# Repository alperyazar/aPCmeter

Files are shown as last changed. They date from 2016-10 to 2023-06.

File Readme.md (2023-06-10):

# aPCmeter

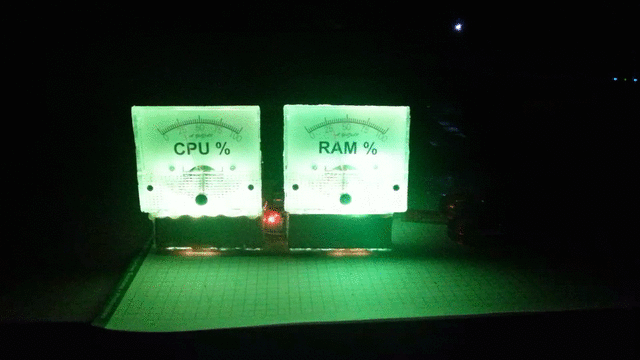
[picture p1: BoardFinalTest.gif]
aPCmeter Working


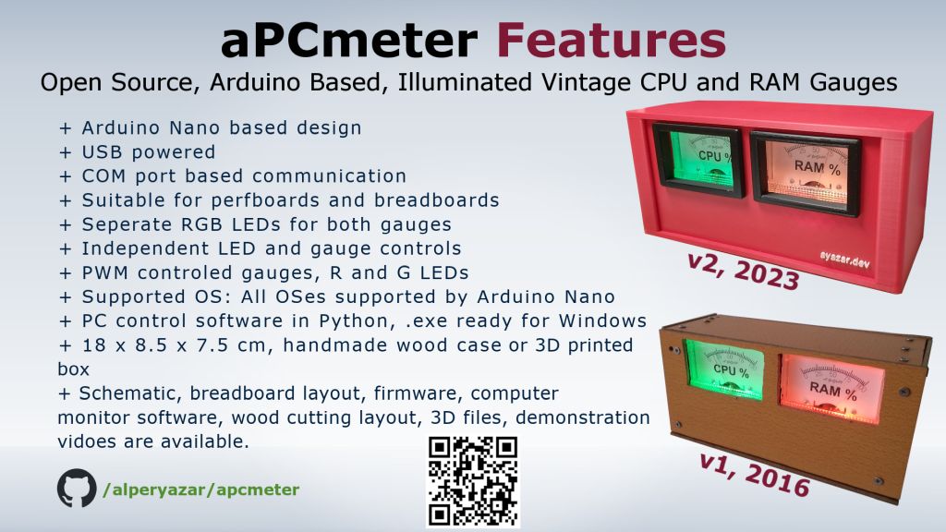
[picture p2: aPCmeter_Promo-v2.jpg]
aPCmeter Flyer


aPCmeter is an open source, Arduino Nano based, illuminated vintage looking CPU and RAM gauges box project. It was designed only just for fun. It shows CPU and RAM utilization of PC in an analog manner.

**AS IS, ABSOLUTELY NO WARRANTY**

## v2, 2023

7 years after the first design (v1, 2016), my friend [Erdal Mehmetcik](https://www.linkedin.com/in/erdal-mehmetcik-7470363a/) who is a 3D printer enthusiast designed and printed an ABS box for me (with [Bambu X1c](https://bambulab.com/en/x1)) and I did a *retrofit*.

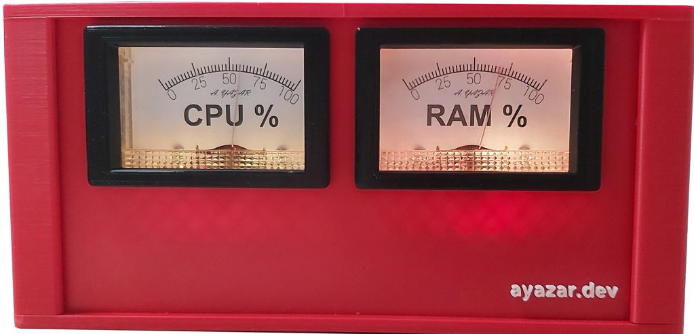
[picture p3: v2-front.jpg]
v2 front


## v2, 2023 vs v1, 2016

The only difference between v2 and v1 is the box design. When I created the project in 2016, 3D printers were not widespread. Therefore, I made a wooden box. In 2023, the box is upgraded to a 3D printed ABS. The electronics, firmware and software are the same.

## Folders

* `3D`: `.stl` files of the new box (v2). You can create your own copy with a 3D printer.

* `Board`: Contains schematic and bread board layout drawn by using Fritzing, BOM and Arduino Nano pinout diagram.

* `Firmware`: Contains Arduino software and its documentation generated by using Doxygen. Doxygen codes are also included there.

* `HowToBuild`: Contains detailed building guide for the hardware.

* `Gauge`: Contains drawings of CPU and RAM gauges in both vector and static formats. All vector drawings were done in Inkscape.

* `Software`: Contains PC software (Python script + `.exe`) required getting CPU and RAM usages from OS and sending them to aPCmeter.

* `Wood`: Contains wood cut sketch prepared by using simple-cutting-software-x. You may take these drawings as a reference if you are planning to build your own wood case.

## Building your own aPCmeter

This is a basic project. First read `HowToBuild`. The schematic is in `Board` directory. The necessary Arduino firmware is in `Firmware` directory with a very detailed documentation. An example PC software is in `Software` directory. If you want to print your own plastic box, then check `3D` directory or for check `Wood` directory to make your own wooden box.

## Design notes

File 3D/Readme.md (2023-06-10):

# 3D

Here, `.stl` files required to print the v2, 2023 box design by a 3D printer are given. The box was designed by my friend, [Erdal Mehmetcik](https://www.linkedin.com/in/erdal-mehmetcik-7470363a/).

- `body.stl`

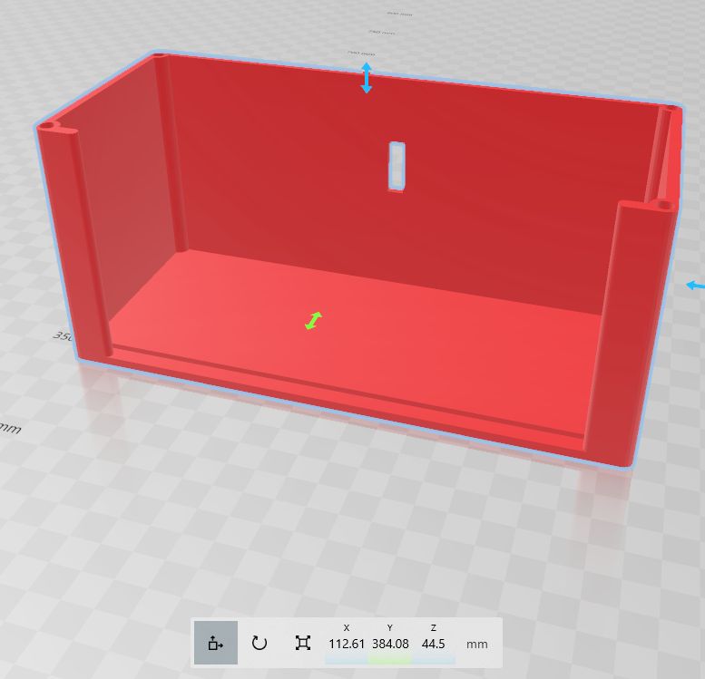
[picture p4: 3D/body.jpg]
body


- `bottom.stl`

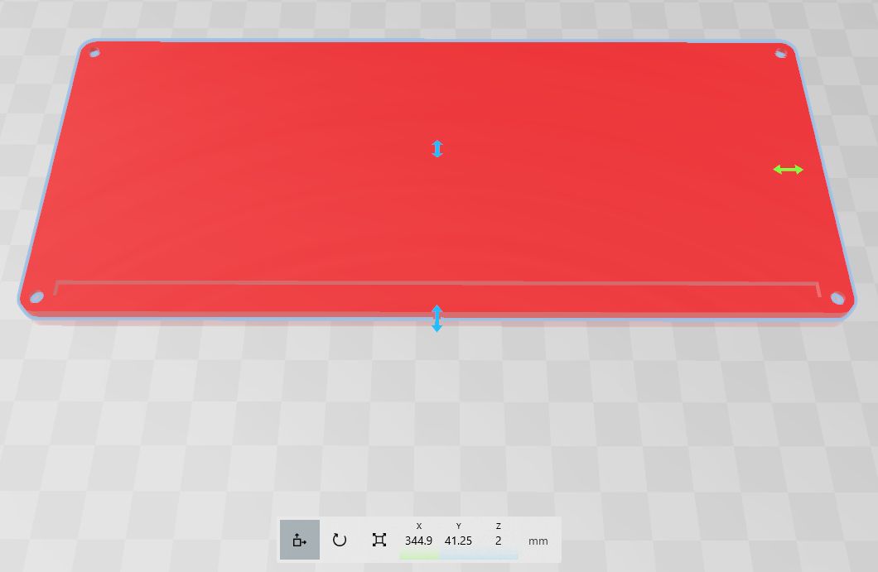
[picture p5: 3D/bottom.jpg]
bottom


- `front.stl`

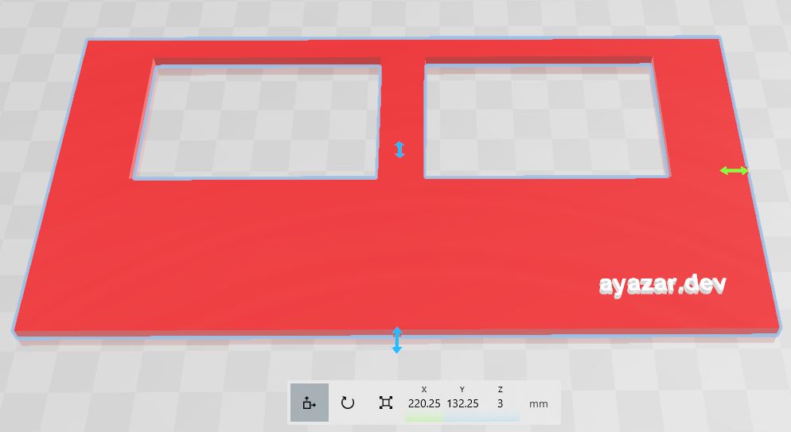
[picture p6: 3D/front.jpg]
front


- `eye.stl`

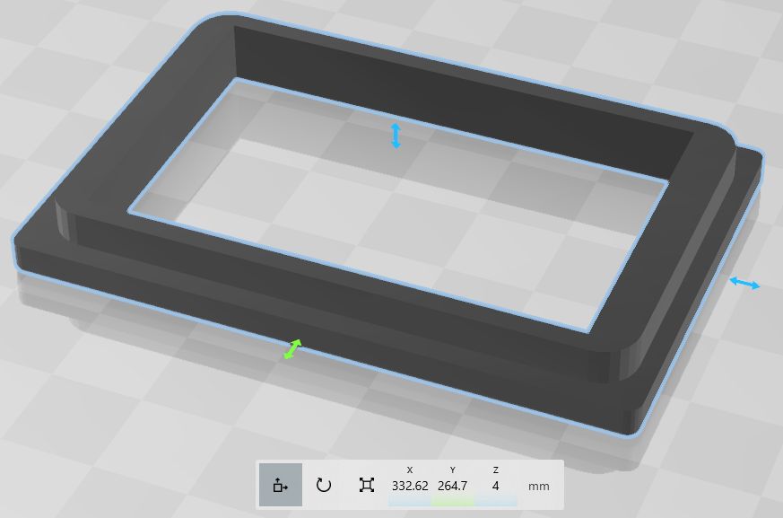
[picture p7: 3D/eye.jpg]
eye


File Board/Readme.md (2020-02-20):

# Board Folder

This folder includes circuit schematic and necessary hardware files.

Circuit schematic and layout is drawn using Fritzing 0.9.2.

## Files

* `aPCmeter_sch.fzz`: Fritzing project file containing schematic and breadboard layout.
* `aPCmeter_sch_bb.[pdf png svg]`: An example breadboard layout generated using Fritzing.
* `aPCmeter_sch_bom.html`: Auto generated BOM file from Fritzing. It is given as reference, please don't consider tolerance etc. vales, just use  values.
* `aPCmeter_sch_schem.pdf`: Schematic of the hardware drawn in Fritzing.
* `nano_pinout.pdf`: Pinout of Arduino Nano 3 given as reference.

***Note to myself:*** aPCmeter_sch_bom.html contains full path of project file. Don't forget to delete it.

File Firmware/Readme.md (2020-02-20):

# Firmware Folder

This folder contains Arduino firmware and code documentation.

## Sub folders and files

* `aPCmeter/aPCmeter.ino`: Arduino sketch file. It is the source code. For this moment, it is tested using Arduino Software 1.6.7.
* `aPCmeter/aPCmeter.pdf`: Documentation of Arduino firmware. It is generated by Doxygen 1.8.11.
* `doxygen`: This folder contains necessary file for Doxygen documentation. LaTeX (pdflatex) should be installed on the system to generate aPCmeter.pdf file.

***Note to myself:*** After generating new doxygen documentation, all output files are generated on doxygen out folder. This folder is ignored by Git. Final output (refman.pdf) should be coppied as aPCmeter/aPCmeter.pdf.

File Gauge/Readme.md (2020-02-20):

# Gauge Folder

This folder contains necessary drawings to customize gauges. Please refer to `HowToBuild` folder for detailed step by step instructions.

Gauges are designed for a specific type of gauge mentioned in `HowToBuild`. You have to scale designs if you are using gauges with different dimensions.

I used 0-5 V analog DC multimeter as gauge. 0.5V is mapped to 0% and 4.5V is mapped tı 100% utilization. There are two reasons behind this decision. 1) In case of problem with aPCmeter it is possible to understand it easily because needles fall below 0% even if CPU utilization is near 0%. 2) Gauges are driven using PWM. Maximum output voltage of Arduino Nano is 5V too. However, I am not sure whether it is possible to obtain 5V while driving it 100% duty cycle. Also gauges are cheap and scale may not be correct. Therefore I mapped 4.5V to 100% not to have any scale problem.

## Files

* `.svg`: These are vector files of gauge desings. Gauges are designed using Inkscape. I didn't used Inkscape before. Simply I tried to follow this tutorial: [http://goinkscape.com/how-to-create-a-tachometer-in-inkscape/](http://goinkscape.com/how-to-create-a-tachometer-in-inkscape/) It is interesting that when I open this files again, numbers on the gauges seem to be missing. You should add these numbers if you want to edit this file. Sorry for this. I don't know whether it is my fault to save correct design folder or bug of Inkscape. Anyway, there are ready-to-print files. You don't have to open Inkscape. Inkscape part of this project is the harderst one for me.
* `ayazar_gauges_A4.pdf`: This is ready-to-print file for gauges. Just print it on white A4 paper and cut them by hand.
* `gauge_cpu.png`, `gauge_ram.png`: Gauge designs without my signature. Background is transparent. Be cautious about dimension, don't print it directly.
* `gauge_cpu_ayazar.png`, `gauge_ram_ayazar.png`: Gauge designs with my signature. Background is white. Be cautious about dimension, don't print it directly.

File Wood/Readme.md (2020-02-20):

# Wood Folder

This folder contains necessary design files to cut wood plates. As stated in `howtobuild.html` in `HowToBuild*`this a very basic template. You should improvise to build a complete box. I used wood an ordinary wood plate with thickness 0.25cm.

## Files

* `pcmeter_wood_simple_cutting.xml`: I used a software called **simple-cutting-software-x.exe 2016.01.17.0 trial version** to find optimum layout for wood cut. Trial version was sufficient for me. You can downlad it from [http://www.nesting-technologies.com/simple-cutting-software-x-en.html](http://www.nesting-technologies.com/simple-cutting-software-x-en.html). This is the project file.

* `WoodCuttingLayout.png`:  This is the layout optimized by the software. Wood thickness is taken as 0.25cm.

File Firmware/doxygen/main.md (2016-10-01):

# What is aPCmeter? # {#mainpage}

aPCmeter is Arduino Nano 3.0 based device which shows CPU and RAM usage of PC in a vintage looking way. Here there are some features of the board. Although I included some photos of the hardware, this document is dedicated to the Arduino firmware.

@note For the most up-to-date information, please check the project webpage http://www.alperyazar.com/r/aPCmeter

@image latex aPCmeter_Promo.png

Since my wood working ability is very limited, it has a crude looking wood case.

@image latex aPCmeter_white_annotated_1024_721.jpg My Ugly aPCmeter
@image latex  aPCmeter_1.jpg
@image latex  aPCmeter_2.jpg
@image latex  aPCmeter_6.jpg

# The Overall System Structure # {#the_overall_system_structure}

The overall structure is very simple. A software running on PC computes CPU and RAM usage percentages. Notice that both CPU and RAM gauges have lighting. Each gauges has its own RGB LED. For example if CPU usage is low, its gauge is illuminated by only green LED. As CPU usage increases, it is illuminated by both red and green LED resulting a yellow light. In addition to CPU and RAM usage information, PC software calculates lighting. Gauge position and lighting information are independent for Arduino software. PC software sends data over USB based virtual COM port and Arduino displays them. This is how Arduino code works basically.

@note For available PC software, please check the project webpage http://www.alperyazar.com/r/aPCmeter Wtihout a proper PC software, aPCmeter hardware can't work properly.

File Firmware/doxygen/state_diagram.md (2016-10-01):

# State Diagram # {#states}

State diagram is shown in the following figure.

@dotfile state_diagram.gv

Explanations of the states are given as below.

State  | Explanation
------------- | -------------
Reset  | This is the state after power up. Also setting the program counter (PC) to zero will reset the CPU. @see resetFunc()
Wait  | aPCmeter enters this state after Reset immediately. In this state, "aPCmeter\r\n" message is sent over serial channel. After the message is sent, aPCmeter waits a response from PC. If no response is received within 2 seconds, 4 pseudo random numbers are generated for PWM values of red LED of CPU gauge, green LED of CPU gauge, red LED of RAM gauge and green LED of RAM gauge. Similarly, 2 pseudo random binary numbers are generated for blue LED of CPU gauge and blue LED of RAM gauge. Using this generated numbers, gauges are illuminated in a pseudo random manner. Gauges stay unpowered completely. Then, the message is sent again. This loop continues for 60 seconds at most. If a valid message is received from the PC, connection is considered to be established. If no valid message is received within 60 seconds, _no PC timeout_ is occured and the state is changed from Wait to Silent Wait. @see #_NO_PC_TIMEOUT @see #_UART_TIMEOUT_ms @see wait_for_connection().
Silent Wait | This state is very similar to Wait state. The differences are as in follows. In Silent Wait state, green and blue LEDs of both gauges become off. Brightness of both red LEDs are changed at every 2 seconds pseudo randomly. As in Wait state, "aPCmeter\r\n" message is sent over serial channel and a valid response is expected. However, Silent Wait state continues until a valid response is received. Notice that Wait and Silent Wait states are almost the same. Purpose of the Wait state is to indicate that aPCmeter is running and is waiting a connection response from PC. Also all LEDs are illimunated in pseudo random manner to test all of them. If aPCmeter is powerd up but no PC software gives a response, changing colors of gauges continuously may disturb people around aPCmeter. Therefore aPCmeter enters in Silen Wait mode after 60 seconds. If you look at directly, you may see that it still tries to connect to PC. @see wait_for_connection()
Active | This is the state where aPCmeter does its job. After connection is established, aPCmeter works in active state until power is removed. The serial communciation protocol between Arduino and PC is given in the following chapters. In this state, maximum duration between two consecutive successful command should be less than 2 seconds. If aPCmeter doesn't receive a successful command within 60 seconds, it resets itself. @see loop() @see #_NO_CMD_TIMEOUT @see #_UART_TIMEOUT_ms

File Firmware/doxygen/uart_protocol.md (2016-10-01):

# UART Protocol # {#uart}

UART protocol works on 9600/8-N-1.

aPCmeter is a command driven device. In other words, PC software sends commands to aPCmeter, it does its job and acknowledges the PC software. Next command should send after the previous one is acknowledged. Each command starts with a capital letter followed by data of command and ends with small case of the starting letter. If it is desired after the last small case letter 'E' character can be send. E stands for end. When aPCmeter receives the 'E' character, it starts to parse the command immediately. If no 'E' is sent after the command, aPCmeter may wait at most 2 seconds before start to process the sent command. It is advised to end all comands with 'E' to trigger the command processing.

Here is the list of all possible messages:

## Hello Mesage (Dir: aPCmeter -> PC)
A hello message is sent from aPCmeter when it is in Wait or Silent Wait state periodically. Here is the message: "aPCmeter\r\n", total of 10 bytes. If PC software ready, it should respond with Start Message.

## Start Message (Dir: PC -> aPCmeter)
This message is meaningful when aPCmeter is in Wait or Silent Wait state. It should be send from the PC when aPCmeter sends the Hello Message. It consists of 2 (+1 optional ending) bytes

Byte 1 | Byte 2 | Byte 3 
------ | ------ | ----------------
'S'    | 's'    | 'E' (Optional)

Response from the aPCmeter:

Byte 1 | Byte 2 | Byte 3 | Byte 4 
------ | ------ | ------ | ------
'O'    | 'K'    | '\\r'   | '\\n'

After the response, LEDs of both gauges stay at green. aPCmeter enters to the Active state and the all following commands may be send without any particular order. In Active state, the PC software should send the following commands with period no less than 2 seconds.

## PWM Message (Dir: PC -> aPCmeter)
This is the main message to use aPCmeter. It is used to change PWM values of gauges and LEDs. Here is the structure

Byte Number | Message |
------ | ------ 
1   | 'P'
2-4 | PWM value of red LED of CPU gauge
5-7 | PWM value of green LED of CPU gauge
8-10 | PWM value of CPU gauge
11-13 | PWM value of red LED of RAM gauge
14-16 | PWM value of green LED of RAM gauge
17-19 | PWM value of RAM gauge
20 | 'p'
21 | 'E' (Optional)

Each PWM value is 3 byte length string without null termination like "100", "001", "245". Values should between 0 and 255 (including the both limits) otherwise they are truncated. All PWM values are updated with this command. This is the way to change color and position of gauges.

For LEDs, "000" corresponds to full bright LED and "255" corresponds to completely off LED. For gauges, it is the opposite. "000" corresponds to no movement whereas "255" corresponds to full deflection.

Response from the aPCmeter:

Byte 1 | Byte 2 | Byte 3 | Byte 4 
------ | ------ | ------ | ------
'O'    | 'K'    | '\\r'   | '\\n'

## Test Message(Dir: PC -> aPCmeter)
It is used to start built-in self-test routine. In this routine both gauges are moved slowly and color of gauges are changed slowly. This may be used to check functional operation of aPCmeter.

Byte 1 | Byte 2 | Byte 3 
------ | ------ | ----------------
'T'    | 't'    | 'E' (Optional)

Response from the aPCmeter after self-test:

Byte 1 | Byte 2 | Byte 3 | Byte 4 
------ | ------ | ------ | ------
'O'    | 'K'    | '\\r'   | '\\n'

## Blue Message(Dir: PC -> aPCmeter)

Blue LEDs are not PWM driven and they are not controlled by the PWM command. There are seperate command for blue LEDs just to turn them on or off seperately. 

Byte 1 | Byte 2 | Byte 3 | Byte 4 | Byte 5 
------ | ------ | ------ | ------ | ------
'B'    | 'B'    | CPU Blue LED     | RAM Blue LED | 'E' (Optional)

x Blue LED: Controls the blue LED of the x gauge. If the corresponding byte is '1', the corresponding blue LED becomes on. Similarly, if the byte is '0' the corresponding LED becomes off.

Response from the aPCmeter:

Byte 1 | Byte 2 | Byte 3 | Byte 4 
------ | ------ | ------ | ------
'O'    | 'K'    | '\\r'   | '\\n'

## Reset Message(Dir: PC -> aPCmeter)
It is used to reset the aPCmeter. State is changed from Active to Reset after this command.

Byte 1 | Byte 2 | Byte 3 
------ | ------ | ----------------
'R'    | 'r'    | 'E' (Optional)

Response from the aPCmeter:

Byte 1 | Byte 2 | Byte 3 | Byte 4 
------ | ------ | ------ | ------
'O'    | 'K'    | '\\r'   | '\\n'

## Keep Alive Message(Dir: PC -> aPCmeter)
It is used to avoid _No CMD Timouet_. As stated previously, PC software should send messages to aPCmeter periodically to avoid timeout. If PC software has nothing to say, it can just send Keep Alive Message. It does nothing except avoiding timeout.

Byte 1 | Byte 2 | Byte 3 
------ | ------ | ----------------
'K'    | 'k'    | 'E' (Optional)

Response from the aPCmeter:

Byte 1 | Byte 2 | Byte 3 | Byte 4 
------ | ------ | ------ | ------
'O'    | 'K'    | '\\r'   | '\\n'

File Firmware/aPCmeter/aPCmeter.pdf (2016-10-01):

## aPCmeter Firmware

s1

Generated by Doxygen 1.8.11

Thu Jul 14 2016 21:05:04

CONTENTS | 1

## Contents

1 What is aPCmeter? | 2
2 State Diagram | 6
3 UART Protocol | 7
4 Bug List | 10
5 File Index | 10
6 File Documentation | 10
Index | 27

Generated on Thu Jul 14 2016 21:05:04 for aPCmeter Firmware by Doxygen

### 2 CONTENTS

## 1 What is aPCmeter?

aPCmeter is Arduino Nano 3.0 based device which shows CPU and RAM usage of PC in a vintage looking way. Here there are some features of the board. Although I included some photos of the hardware, this document is dedicated to the Arduino firmware.

Note

For the most up-to-date information, please check the project webpage http://www.alperyazar.←-com/r/aPCmeter (http://www.alperyazar.com/r/aPCmeter)

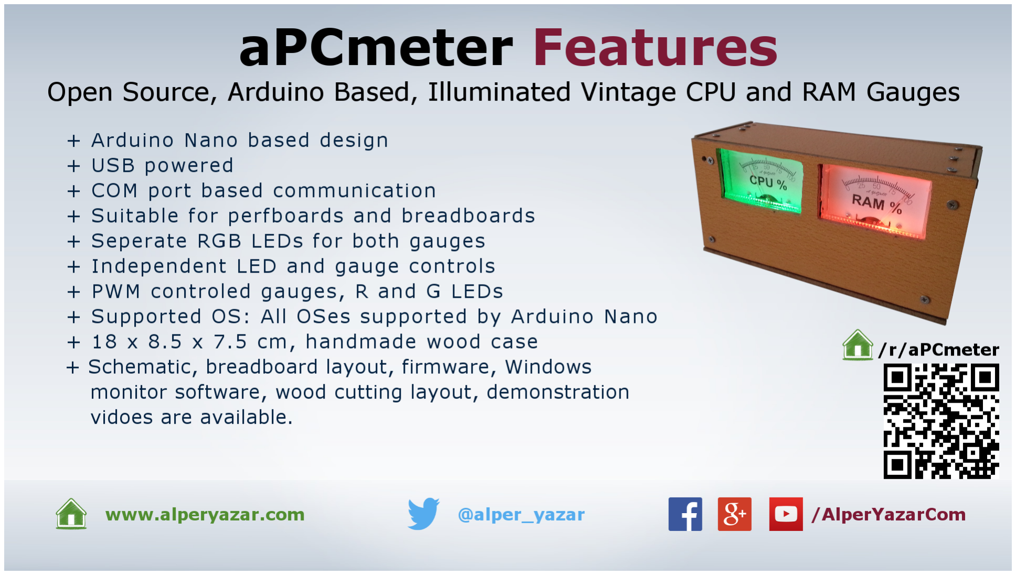
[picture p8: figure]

Since my wood working ability is very limited, it has a crude looking wood case.

1 What is aPCmeter? | 3

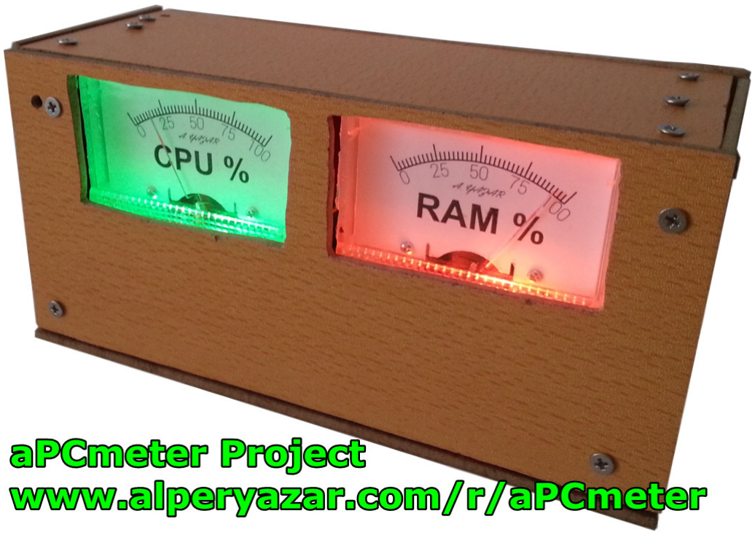
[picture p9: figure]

Figure 1 My Ugly aPCmeter

### 4 CONTENTS

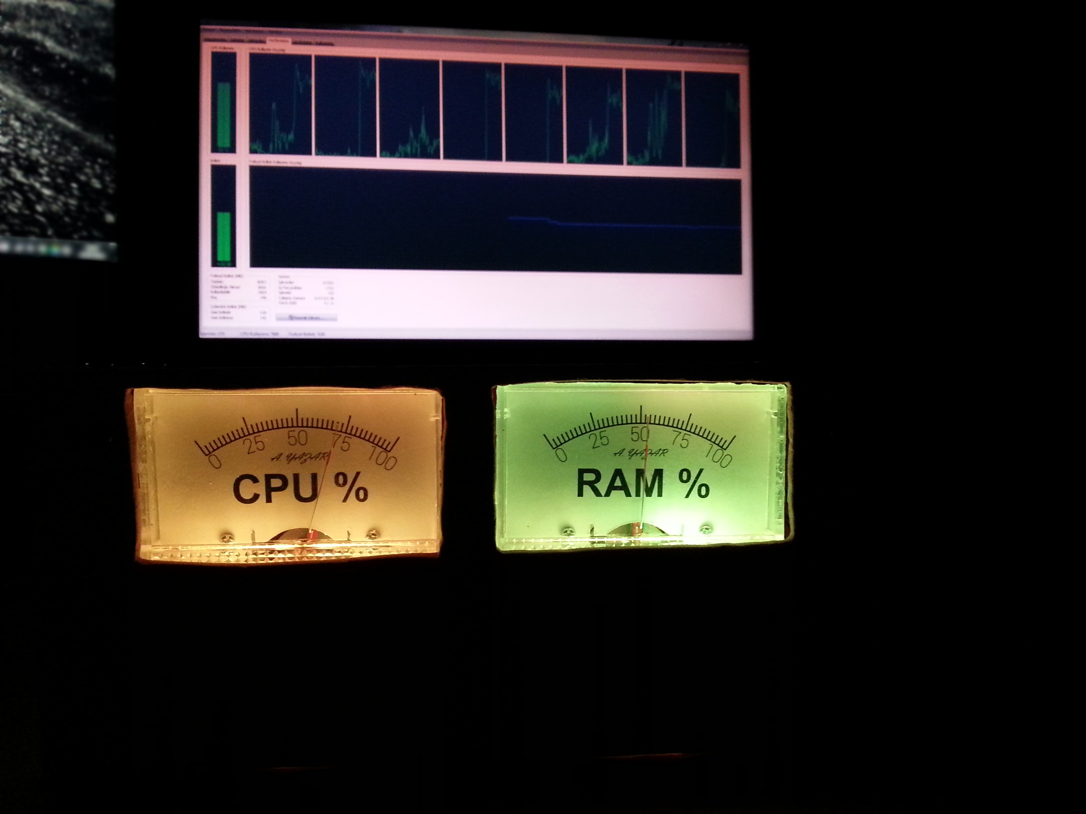
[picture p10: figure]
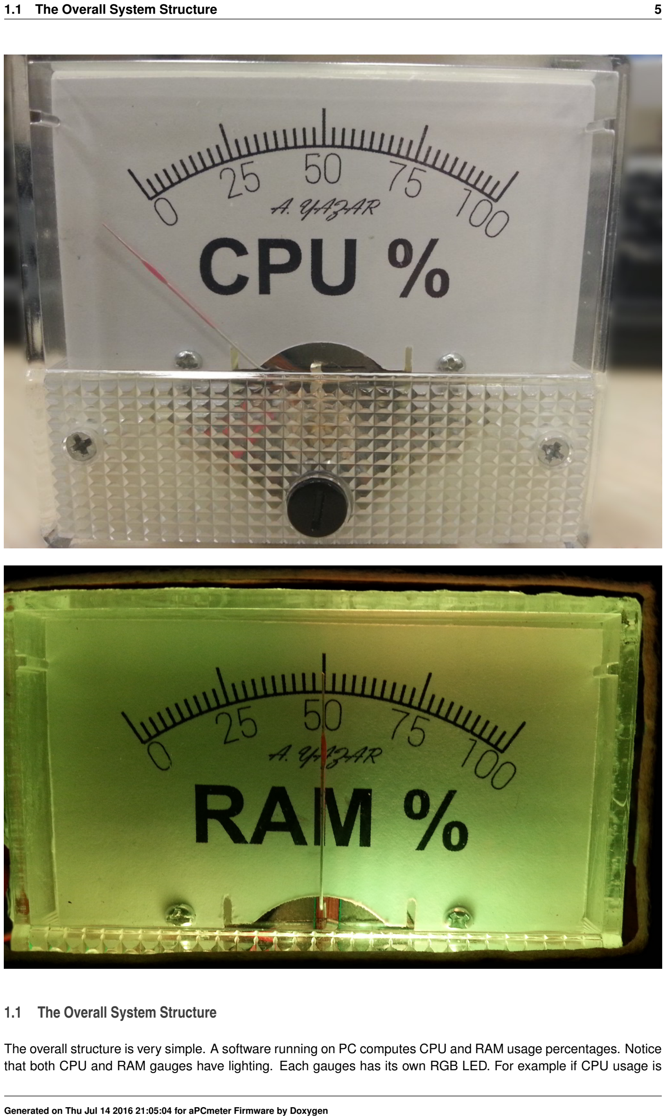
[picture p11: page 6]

1.1 The Overall System Structure | 5

### 1.1 The Overall System Structure

The overall structure is very simple. A software running on PC computes CPU and RAM usage percentages. Notice that both CPU and RAM gauges have lighting. Each gauges has its own RGB LED. For example if CPU usage is

### 6 CONTENTS

low, its gauge is illuminated by only green LED. As CPU usage increases, it is illuminated by both red and green LED resulting a yellow light. In addition to CPU and RAM usage information, PC software calculates lighting. Gauge position and lighting information are independent for Arduino software. PC software sends data over USB based virtual COM port and Arduino displays them. This is how Arduino code works basically.

Note

For available PC software, please check the project webpage http://www.alperyazar.com/r/aP←-Cmeter (http://www.alperyazar.com/r/aPCmeter) Wtihout a proper PC software, aPCmeter hardware can't work properly.

## 2 State Diagram

State diagram is shown in the following figure.

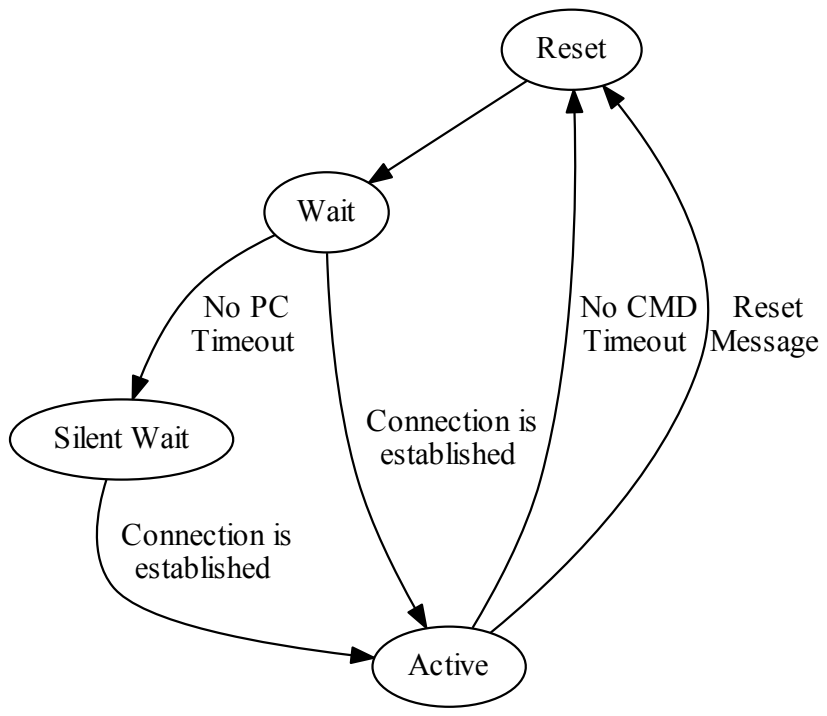
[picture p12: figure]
Reset; Wait; Silent Wait; No PC Timeout; Active; Connection is established; No CMD Timeout; Reset Message

Explanations of the states are given as below.

State | Explanation
Reset | This is the state after power up. Also setting the program counter (PC) to zero will reset the CPU. See also resetFunc()

3 UART Protocol | 7
State | Explanation
Wait | aPCmeter enters this state after Reset immediately. In this state, "aPCmeter\r\n" message is sent over serial channel. After the message is sent, aPCmeter waits a response from PC. If no response is received within 2 seconds, 4 pseudo random numbers are generated for PWM values of red L←- ED of CPU gauge, green LED of CPU gauge, red LED of RAM gauge and green LED of RAM gauge. Similarly, 2 pseudo random binary numbers are generated for blue LED of CPU gauge and blue LED of RAM gauge. Using this generated numbers, gauges are illuminated in a pseudo random manner. Gauges stay unpowered completely. Then, the message is sent again. This loop continues for 60 seconds at most. If a valid message is received from the PC, connection is considered to be established. If no valid message is received within 60 seconds, no PC timeout is occured and the state is changed from Wait to Silent Wait.
| See also
| _NO_PC_TIMEOUT _UART_TIMEOUT_ms wait_for_connection().
Silent Wait | This state is very similar to Wait state. The differences are as in follows. In Silent Wait state, green and blue LEDs of both gauges become off. Brightness of both red LEDs are changed at every 2 seconds pseudo randomly. As in Wait state, "aPCmeter\r\n" message is sent over serial channel and a valid response is expected. However, Silent Wait state continues until a valid response is received. Notice that Wait and Silent Wait states are almost the same. Purpose of the Wait state is to indicate that aPCmeter is running and is waiting a connection response from PC. Also all LEDs are illimunated in pseudo random manner to test all of them. If aPCmeter is powerd up but no PC software gives a response, changing colors of gauges continuously may disturb people around aPCmeter. Therefore aPCmeter enters in Silen Wait mode after 60 seconds. If you look at directly, you may see that it still tries to connect to PC.
| See also
| wait_for_connection()
Active | This is the state where aPCmeter does its job. After connection is established, aPCmeter works in active state until power is removed. The serial communciation protocol between Arduino and PC is given in the following chapters. In this state, maximum duration between two consecutive successful command should be less than 2 seconds. If aPCmeter doesn't receive a successful command within 60 seconds, it resets itself.
| See also
| loop() _NO_CMD_TIMEOUT _UART_TIMEOUT_ms

## 3 UART Protocol

UART protocol works on 9600/8-N-1.

aPCmeter is a command driven device. In other words, PC software sends commands to aPCmeter, it does its job and acknowledges the PC software. Next command should send after the previous one is acknowledged. Each command starts with a capital letter followed by data of command and ends with small case of the starting letter. If it is desired after the last small case letter 'E' character can be send. E stands for end. When aPCmeter receives the 'E' character, it starts to parse the command immediately. If no 'E' is sent after the command, aPCmeter may wait at most 2 seconds before start to process the sent command. It is advised to end all comands with 'E' to trigger the command processing.

Here is the list of all possible messages:

### 8 CONTENTS

Hello Mesage (Dir: aPCmeter -> PC)

A hello message is sent from aPCmeter when it is in Wait or Silent Wait state periodically. Here is the message: "aPCmeter\r\n", total of 10 bytes. If PC software ready, it should respond with Start Message.

Start Message (Dir: PC -> aPCmeter)

This message is meaningful when aPCmeter is in Wait or Silent Wait state. It should be send from the PC when aPCmeter sends the Hello Message. It consists of 2 (+1 optional ending) bytes

Byte 1 | Byte 2 | Byte 3
'S' | 's' | 'E' (Optional)

Response from the aPCmeter:

Byte 1 | Byte 2 | Byte 3 | Byte 4
'O' | 'K' | '\r' | '\n'

After the response, LEDs of both gauges stay at green. aPCmeter enters to the Active state and the all following commands may be send without any particular order. In Active state, the PC software should send the following commands with period no less than 2 seconds.

PWM Message (Dir: PC -> aPCmeter)

This is the main message to use aPCmeter. It is used to change PWM values of gauges and LEDs. Here is the structure

Byte Number | Message
1 | 'P'
2-4 | PWM value of red LED of CPU gauge
5-7 | PWM value of green LED of CPU gauge
8-10 | PWM value of CPU gauge
11-13 | PWM value of red LED of RAM gauge
14-16 | PWM value of green LED of RAM gauge
17-19 | PWM value of RAM gauge
20 | 'p'
21 | 'E' (Optional)

Each PWM value is 3 byte length string without null termination like "100", "001", "245". Values should between 0 and 255 (including the both limits) otherwise they are truncated. All PWM values are updated with this command. This is the way to change color and position of gauges.

For LEDs, "000" corresponds to full bright LED and "255" corresponds to completely off LED. For gauges, it is the opposite. "000" corresponds to no movement whereas "255" corresponds to full deflection.

Response from the aPCmeter:

3 UART Protocol | 9
Byte 1 | Byte 2 | Byte 3 | Byte 4
'O' | 'K' | '\r' | '\n'

Test Message(Dir: PC -> aPCmeter)

It is used to start built-in self-test routine. In this routine both gauges are moved slowly and color of gauges are changed slowly. This may be used to check functional operation of aPCmeter.

Byte 1 | Byte 2 | Byte 3
'T' | 't' | 'E' (Optional)

Response from the aPCmeter after self-test:

Byte 1 | Byte 2 | Byte 3 | Byte 4
'O' | 'K' | '\r' | '\n'

Blue Message(Dir: PC -> aPCmeter)

Blue LEDs are not PWM driven and they are not controlled by the PWM command. There are seperate command for blue LEDs just to turn them on or off seperately.

Byte 1 | Byte 2 | Byte 3 | Byte 4 | Byte 5
'B' | 'B' | CPU Blue LED | RAM Blue LED | 'E' (Optional)

x Blue LED: Controls the blue LED of the x gauge. If the corresponding byte is '1', the corresponding blue LED becomes on. Similarly, if the byte is '0' the corresponding LED becomes off.

Response from the aPCmeter:

Byte 1 | Byte 2 | Byte 3 | Byte 4
'O' | 'K' | '\r' | '\n'

Reset Message(Dir: PC -> aPCmeter)

It is used to reset the aPCmeter. State is changed from Active to Reset after this command.

Byte 1 | Byte 2 | Byte 3
'R' | 'r' | 'E' (Optional)

Response from the aPCmeter:

Byte 1 | Byte 2 | Byte 3 | Byte 4
'O' | 'K' | '\r' | '\n'

### 10 CONTENTS

Keep Alive Message(Dir: PC -> aPCmeter)

It is used to avoid No CMD Timouet. As stated previously, PC software should send messages to aPCmeter periodically to avoid timeout. If PC software has nothing to say, it can just send Keep Alive Message. It does nothing except avoiding timeout.

Byte 1 | Byte 2 | Byte 3
'K' | 'k' | 'E' (Optional)

Response from the aPCmeter:

Byte 1 | Byte 2 | Byte 3 | Byte 4
'O' | 'K' | '\r' | '\n'

## 4 Bug List

File aPCmeter.ino
Visit: https://github.com/alperyazar/aPCmeter/issues to check existing bugs or to report a new one.

## 5 File Index

### 5.1 File List

Here is a list of all files with brief descriptions:

aPCmeter.ino
APCmeter Project, source code of Arduino firmware | 10

## 6 File Documentation

### 6.1 aPCmeter.ino File Reference

aPCmeter Project, source code of Arduino firmware.

Macros

- #define _NO_CMD_TIMEOUT 29

Determines the maximum trials between two consecutive command reception in active state before reset.
- #define _NO_PC_TIMEOUT 29

Determines the duration of wait state after reset.
- #define _UART_TIMEOUT_ms 2000

Receive timeout value in msec for serial channel receive function.
- #define _UART_BAUD_RATE 9600

Baud rate for serial communication in bps.

6.1 aPCmeter.ino File Reference | 11

Functions

- void setup ()

This function is called after startup. Like a well known main() function in C.
- void wait_for_connection ()

Wait proper connection initialization from PC.
- void loop ()

This function is automatically after setup(). Loops forever...
- int str2duty (const char ∗str)

Converted string to integer. (Ex: "105" -> 105)
- void set_duty (int channel, int duty)

Set duty cycle for red, green LED and gauge for a channel.
- void self_test ()

BIST (built-in self-test)

Variables

- const int redPinCPU = 3

Pin number of red LED of CPU gauge.
- const int greenPinCPU = 5

Pin number of green LED of CPU gauge.
- const int bluePinCPU = 2

Pin number of blue LED of CPU gauge.
- const int gaugePinCPU = 6

Pin number of CPU gauge.
- const int redPinRAM = 9

Pin number of red LED of RAM gauge.
- const int greenPinRAM = 10

Pin number of green LED of RAM gauge.
- const int bluePinRAM = 19

Pin number of blue LED of RAM gauge.
- const int gaugePinRAM = 11

Pin number of RAM gauge.
- char RX_buf [64]

Receive buffer for serial channel.
- void(∗ resetFunc )(void)=0

Tricky reset function. Just set PC to 0.

### 6.1.1 Detailed Description

aPCmeter Project, source code of Arduino firmware.

This single file contains all source code of aPCmeter Arduino Nano firmware. It is tested by using Arduino IDE v1.6.7 on Windows 7 x64.

Author

Alper Yazar

### 12 CONTENTS

Version

s1

Date

2016-05-08

Copyright

CC BY-NC-SA 4.0 (http://creativecommons.org/licenses/by-nc-sa/4.0/)

Bug Visit: https://github.com/alperyazar/aPCmeter/issues to check existing bugs or to report a new one.

Warning

NO WARRANTY! AS IS!

See also

The Official Project Page: http://www.alperyazar.com/r/aPCmeter

Definition in file aPCmeter.ino.

### 6.1.2 Macro Definition Documentation

6.1.2.1 #define _NO_CMD_TIMEOUT 29

Determines the maximum trials between two consecutive command reception in active state before reset.

When aPCmeter is in active state, it waits commands from PC. PC software should send commands with period less than _UART_TIMEOUT_ms to avoid time out. If no valid message is received within _UART_TIMEOUT_ms msec after the last successfully received command, a timeout counter is incremented by one. If value of this counter exceeds _NO_CMD_TIMEOUT, aPCmeter resets itself.

See also

loop()

Maximum duration between two successful message before reset in msec = (#_NO_CMD_TIMEOUT + 1) x #_UART_TIMEOUT_ms

Warning

It should be a non-negative integer.

Definition at line 22 of file aPCmeter.ino.

Referenced by loop().

6.1 aPCmeter.ino File Reference | 13

6.1.2.2 #define _NO_PC_TIMEOUT 29

Determines the duration of wait state after reset.

After reset, aPCmeter sends "aPCmeter" message periodically determined by _UART_TIMEOUT_ms. After each message it waits a valid message from PC for the first connection. At each time "aPCmeter" message is sent, a pseudo random color is selected for both CPU and RAM gauges and both gauges are illuminated with the selected color. This is used to indiciate that aPCmeter is looking for a PC connection and to provide pseudo random test pattern sequence for all three channels (R, G, B) of both LEDs. If the number of trials exceeds the threshold value determined by _NO_PC_TIMEOUT, aPCmeter enters to the silent wait state. In that state, G and B LEDs of both gauges become off. Only brightness of R LEDs of both gauges is changed in a pseudo random manner. This is done to avoid disturbing color changes when all R, G, B LEDs are illuminated pseudo randomly. This may be the case when aPCmeter is left connected to the PC or another USB host device. However brightness of red LEDs continues to change and aPCmeter looks a PC connection for ever. One may still be able to notice that aPCmeter is active since brightness of red LEDs is changed periodically.

Note

Duration of wait state can be calculated as follow

Duration of wait state in msec = (#_NO_PC_TIMEOUT + 1) x #_UART_TIMEOUT_ms

Warning

It should be a non-negative integer.

See also

wait_for_connection()

Definition at line 32 of file aPCmeter.ino.

Referenced by wait_for_connection().

6.1.2.3 #define _UART_BAUD_RATE 9600

Baud rate for serial communication in bps.

See also

setup()

Definition at line 46 of file aPCmeter.ino.

Referenced by setup().

### 14 CONTENTS

6.1.2.4 #define _UART_TIMEOUT_ms 2000

Receive timeout value in msec for serial channel receive function.

aPCmeter waits at most _UART_TIMEOUT_ms msec when serial read functions are called. If no message is received from PC in _UART_TIMEOUT_ms msec, serial receive functions are timed out and code continues. Actually this is basic "tic" source for this code.

Warning

It should be a non-negative integer.

See also

setup()

Definition at line 40 of file aPCmeter.ino.

Referenced by setup().

### 6.1.3 Function Documentation

### 6.1.3.1 void loop ( )

This function is automatically after setup(). Loops forever...

See also

https://www.arduino.cc/en/Reference/Loop

Definition at line 199 of file aPCmeter.ino.

References _NO_CMD_TIMEOUT, bluePinCPU, bluePinRAM, gaugePinCPU, gaugePinRAM, greenPinCPU, greenPinRAM, redPinCPU, redPinRAM, resetFunc, RX_buf, self_test(), and str2duty().

Here is the call graph for this function:

### loop

### self_test

### str2duty

### set_duty

6.1 aPCmeter.ino File Reference | 15

### 6.1.3.2 void self_test ( )

BIST (built-in self-test)

Sweep all LEDs and gauges to make sure that everything is working well.

Definition at line 334 of file aPCmeter.ino.

References bluePinCPU, bluePinRAM, gaugePinCPU, gaugePinRAM, greenPinCPU, greenPinRAM, redPinCPU, redPinRAM, and set_duty().

Referenced by loop().

Here is the call graph for this function:

self_test | set_duty

Here is the caller graph for this function:

self_test | loop

### 6.1.3.3 void set_duty ( int channel, int duty )

Set duty cycle for red, green LED and gauge for a channel.

It is used by BIST (built-in self-test)

Parameters

in | channel | 0 means CPU gauge, 1 means RAM gauge
in | duty | It should be between 0 and 255 (including both). Otherwise, it will be truncated into this range. It is the PWM value for analogWrite() function. 0 corresponds to 0% for gauge, 100% for green and 0% for red.

Definition at line 307 of file aPCmeter.ino.

References gaugePinCPU, gaugePinRAM, greenPinCPU, greenPinRAM, redPinCPU, and redPinRAM.

### 16 CONTENTS

Referenced by self_test().

Here is the caller graph for this function:

set_duty | self_test | loop

### 6.1.3.4 void setup ( )

This function is called after startup. Like a well known main() function in C.

See also

https://www.arduino.cc/en/Reference/Setup

Definition at line 111 of file aPCmeter.ino.

References _UART_BAUD_RATE, _UART_TIMEOUT_ms, bluePinCPU, bluePinRAM, gaugePinCPU, gaugePin←-RAM, greenPinCPU, greenPinRAM, redPinCPU, redPinRAM, and wait_for_connection().

Here is the call graph for this function:

setup | wait_for_connection

### 6.1.3.5 int str2duty ( const char ∗ str )

Converted string to integer. (Ex: "105" -> 105)

PWM information for LEDs and gauges are sent as a text formatted as 3 digit decimal number like "000", "104", "205". This function is used to 3 digit decimal number to its corresponding integere value.

Parameters

in | str | It is a pointer to the string that is converted to integer. It should be 3 digit unsigned decimal value. Null termination doesn't affect the behaviour.

6.1 aPCmeter.ino File Reference | 17

Return values

Integer value is returned. Value is truncated in between 0 and 255.

Definition at line 289 of file aPCmeter.ino.

Referenced by loop().

Here is the caller graph for this function:

str2duty | loop

### 6.1.3.6 void wait_for_connection ( )

Wait proper connection initialization from PC.

Definition at line 146 of file aPCmeter.ino.

References _NO_PC_TIMEOUT, bluePinCPU, bluePinRAM, greenPinCPU, greenPinRAM, redPinCPU, redPinR←-AM, and RX_buf.

Referenced by setup().

Here is the caller graph for this function:

wait_for_connection | setup

### 6.1.4 Variable Documentation

### 6.1.4.1 const int bluePinCPU = 2

Pin number of blue LED of CPU gauge.

See also

http://playground.arduino.cc/Learning/Pins

Definition at line 64 of file aPCmeter.ino.

Referenced by loop(), self_test(), setup(), and wait_for_connection().

### 18 CONTENTS

### 6.1.4.2 const int bluePinRAM = 19

Pin number of blue LED of RAM gauge.

See also

http://playground.arduino.cc/Learning/Pins

Definition at line 88 of file aPCmeter.ino.

Referenced by loop(), self_test(), setup(), and wait_for_connection().

### 6.1.4.3 const int gaugePinCPU = 6

Pin number of CPU gauge.

See also

http://playground.arduino.cc/Learning/Pins

Definition at line 70 of file aPCmeter.ino.

Referenced by loop(), self_test(), set_duty(), and setup().

### 6.1.4.4 const int gaugePinRAM = 11

Pin number of RAM gauge.

See also

http://playground.arduino.cc/Learning/Pins

Definition at line 94 of file aPCmeter.ino.

Referenced by loop(), self_test(), set_duty(), and setup().

### 6.1.4.5 const int greenPinCPU = 5

Pin number of green LED of CPU gauge.

See also

http://playground.arduino.cc/Learning/Pins

Definition at line 58 of file aPCmeter.ino.

Referenced by loop(), self_test(), set_duty(), setup(), and wait_for_connection().

6.1 aPCmeter.ino File Reference | 19

### 6.1.4.6 const int greenPinRAM = 10

Pin number of green LED of RAM gauge.

See also

http://playground.arduino.cc/Learning/Pins

Definition at line 82 of file aPCmeter.ino.

Referenced by loop(), self_test(), set_duty(), setup(), and wait_for_connection().

### 6.1.4.7 const int redPinCPU = 3

Pin number of red LED of CPU gauge.

See also

http://playground.arduino.cc/Learning/Pins

Definition at line 52 of file aPCmeter.ino.

Referenced by loop(), self_test(), set_duty(), setup(), and wait_for_connection().

### 6.1.4.8 const int redPinRAM = 9

Pin number of red LED of RAM gauge.

See also

http://playground.arduino.cc/Learning/Pins

Definition at line 76 of file aPCmeter.ino.

Referenced by loop(), self_test(), set_duty(), setup(), and wait_for_connection().

### 6.1.4.9 void(∗ resetFunc) (void)=0

Tricky reset function. Just set PC to 0.

Definition at line 105 of file aPCmeter.ino.

Referenced by loop().

### 6.1.4.10 char RX_buf[64]

Receive buffer for serial channel.

More than enough actually...

Definition at line 100 of file aPCmeter.ino.

Referenced by loop(), and wait_for_connection().

### 20 CONTENTS

### 6.2 aPCmeter.ino

00001
00022 #define _NO_CMD_TIMEOUT 29 00023
00032 #define _NO_PC_TIMEOUT 29 00033
00040 #define _UART_TIMEOUT_ms 2000 00041
00046 #define _UART_BAUD_RATE 9600 00047
00052 const int redPinCPU = 3; 00053
00058 const int greenPinCPU = 5; 00059
00064 const int bluePinCPU = 2; 00065
00070 const int gaugePinCPU = 6; 00071
00076 const int redPinRAM = 9; 00077
00082 const int greenPinRAM = 10; 00083
00088 const int bluePinRAM = 19; 00089
00094 const int gaugePinRAM = 11; 00095
00100 char RX_buf[64];
00101
00105 void(* resetFunc) (void) = 0; 00106
00111 void setup()
00112 {
00113 | pinMode(gaugePinCPU, INPUT);
00114 | pinMode(gaugePinRAM, INPUT);
00115
00116 | digitalWrite(redPinCPU, HIGH);
00117 | digitalWrite(greenPinCPU, HIGH);
00118 | digitalWrite(bluePinCPU, HIGH);
00119
00120 | digitalWrite(redPinRAM, HIGH);
00121 | digitalWrite(greenPinRAM, HIGH);
00122 | digitalWrite(bluePinRAM, HIGH);
00123
00124 | pinMode(redPinCPU, OUTPUT);
00125 | pinMode(greenPinCPU, OUTPUT);
00126 | pinMode(bluePinCPU, OUTPUT);
00127
00128 | pinMode(redPinRAM, OUTPUT);
00129 | pinMode(greenPinRAM, OUTPUT);
00130 | pinMode(bluePinRAM, OUTPUT);
00131
00132 //All LEDs are off. Gauges are off. 00133
00134 | // Set properties of Serial’s.
00135 | Serial.setTimeout(_UART_TIMEOUT_ms);
00136 | Serial.begin(_UART_BAUD_RATE);
00137 | while (!Serial) {
00138 | ; // wait for serial port to connect. Needed for native USB
00139 | }
00140 | wait_for_connection();
00141 }
00142
00146 void wait_for_connection() 00147 {
00148 int timeout = 0;
00149
00150 | // Try to randomize pseudo-random sequences used by random() funtion.
00151 | randomSeed(analogRead(0));
00152 | while (1)
00153 | {
00154 | Serial.println("aPCmeter");
00155 | if ( Serial.readBytesUntil(’E’, RX_buf, 64) == 0)
00156 | {
00157 | analogWrite(redPinCPU, random(256));
00158 | analogWrite(redPinRAM, random(256));
00159 | analogWrite(greenPinRAM, random(256));
00160 | analogWrite(greenPinCPU, random(256));
00161 | digitalWrite(bluePinCPU, random(2));
00162 | digitalWrite(bluePinRAM, random(2));
00163 | timeout++;
00164 | if (timeout > _NO_PC_TIMEOUT)
00165 | {
00166 | timeout--;
00167 | digitalWrite(greenPinCPU, HIGH);
00168 | digitalWrite(bluePinCPU, HIGH);

6.2 aPCmeter.ino | 21
00169 | digitalWrite(greenPinRAM, HIGH);
00170 | digitalWrite(bluePinRAM, HIGH);
00171 | analogWrite(redPinRAM, 128 + random(128));
00172 | analogWrite(redPinCPU, 128 + random(128));
00173 | }
00174 | }
00175 | else
00176 | {
00177 | if ((RX_buf[0] == ’S’) && (RX_buf[1] == ’s’))
00178 | {
00179 | timeout = 0;
00180 | digitalWrite(redPinCPU, HIGH);
00181 | digitalWrite(redPinRAM, HIGH);
00182 | digitalWrite(bluePinCPU, HIGH);
00183 | digitalWrite(bluePinRAM, HIGH);
00184 | digitalWrite(greenPinCPU, LOW);
00185 | digitalWrite(greenPinRAM, LOW);
00186 | // Both gauges are fully green.
00187 | Serial.println("OK");
00188 | return;
00189 | }
00190 | memset(RX_buf, ’ ’, 64); //Clear all buffer
00191 | }
00192 | }
00193 }
00194
00199 void loop()
00200 {
00201 | int timeout_ctr = 0;
00202 | while (1)
00203 | {
00204 | if ( Serial.readBytesUntil(’E’, RX_buf, 64) == 0)
00205 | {
00206 | timeout_ctr++;
00207 | if (timeout_ctr > _NO_CMD_TIMEOUT)
00208 | {
00209 | resetFunc();
00210 | }
00211 | }
00212 | else
00213 | {
00214 | switch (RX_buf[0])
00215 | {
00216 | case ’P’:
00217 | if (RX_buf[19] == ’p’)
00218 | {
00219 | analogWrite(redPinCPU, str2duty(&(RX_buf[1])));
00220 | analogWrite(greenPinCPU, str2duty(&(RX_buf[4])));
00221 | analogWrite(gaugePinCPU, str2duty(&(RX_buf[7])));
00222 | analogWrite(redPinRAM, str2duty(&(RX_buf[10])));
00223 | analogWrite(greenPinRAM, str2duty(&(RX_buf[13])));
00224 | analogWrite(gaugePinRAM, str2duty(&(RX_buf[16])));
00225 | Serial.println("OK");
00226 | timeout_ctr = 0;
00227 | }
00228 | break;
00229 | case ’T’:
00230 | if (RX_buf[1] == ’t’)
00231 | {
00232 | self_test();
00233 | Serial.println("OK");
00234 | timeout_ctr = 0;
00235 | }
00236 | case ’B’:
00237 | if (RX_buf[3] == ’b’)
00238 | {
00239 | if (RX_buf[1] == ’1’)
00240 | {
00241 | digitalWrite(bluePinCPU, LOW);
00242 | }
00243 | if (RX_buf[1] == ’0’)
00244 | {
00245 | digitalWrite(bluePinCPU, HIGH);
00246 | }
00247 | if (RX_buf[2] == ’1’)
00248 | {
00249 | digitalWrite(bluePinRAM, LOW);
00250 | }
00251 | if (RX_buf[2] == ’0’)
00252 | {
00253 | digitalWrite(bluePinRAM, HIGH);
00254 | }
00255 | Serial.println("OK");
00256 | timeout_ctr = 0;
00257 | }
00258 | case ’R’:
00259 | if (RX_buf[1] == ’r’)

### 22 CONTENTS

00260 | {
00261 | Serial.println("OK");
00262 | timeout_ctr = 0;
00263 | Serial.flush();
00264 | resetFunc();
00265 | }
00266 | case ’K’:
00267 | if (RX_buf[1] == ’k’)
00268 | {
00269 | Serial.println("OK");
00270 | timeout_ctr = 0;
00271 | }
00272 | default:
00273 | timeout_ctr++;
00274 | break;
00275 | }
00276 | memset(RX_buf, ’ ’, 64);
00277 | }
00278
00279 }
00280 }
00281
00289 int str2duty(const char *str) 00290 {
00291 int temp = 0;
00292
00293 | temp = 100 * (str[0] - 0x30);
00294 | temp += 10 * (str[1] - 0x30);
00295 | temp += 1 * (str[2] - 0x30);
00296
00297 return (constrain(temp, 0, 255)); 00298
00299 }
00300
00307 void set_duty(int channel, int duty) 00308 {
00309 // channel 0-> CPU, 1-> RAM 00310
00311 | duty = constrain(duty, 0, 255);
00312 | if (channel == 0)
00313 | {
00314 | analogWrite(gaugePinCPU, duty);
00315 | analogWrite(greenPinCPU, duty);
00316 | analogWrite(redPinCPU, 255 - duty);
00317 | }
00318 | else if (channel == 1)
00319 | {
00320 | analogWrite(gaugePinRAM, duty);
00321 | analogWrite(greenPinRAM, duty);
00322 | analogWrite(redPinRAM, 255 - duty);
00323 | }
00324 | else
00325 | {
00326 | }
00327
00328 }
00329
00334 void self_test()
00335 {
00336 | int duty = 0;
00337 | pinMode(gaugePinCPU, INPUT);
00338 | pinMode(gaugePinRAM, INPUT);
00339 | delay(3000); //Gauges will relax in 3 seconds.
00340 | //Just sweep
00341 | for (duty = 0; duty < 255; duty++)
00342 | {
00343 | analogWrite(gaugePinCPU, duty);
00344 | analogWrite(gaugePinRAM, duty);
00345 | if ( (0 <= duty) && (duty < 85))
00346 | {
00347 | digitalWrite(redPinCPU, HIGH);
00348 | digitalWrite(greenPinCPU, HIGH);
00349 | digitalWrite(bluePinCPU, LOW);
00350
00351 | digitalWrite(redPinRAM, HIGH);
00352 | digitalWrite(greenPinRAM, HIGH);
00353 | digitalWrite(bluePinRAM, LOW);
00354 | }
00355 | if ( (85 <= duty) && (duty < 170))
00356 | {
00357 | digitalWrite(redPinCPU, HIGH);
00358 | digitalWrite(bluePinCPU, HIGH);
00359 | digitalWrite(greenPinCPU, LOW);
00360
00361 | digitalWrite(redPinRAM, HIGH);
00362 | digitalWrite(bluePinRAM, HIGH);
00363 | digitalWrite(greenPinRAM, LOW);

6.3 main.md File Reference | 23

00364
00365 | }
00366 | if ( (170 <= duty) && (duty < 255))
00367 | {
00368 | digitalWrite(greenPinCPU, HIGH);
00369 | digitalWrite(bluePinCPU, HIGH);
00370 | digitalWrite(redPinCPU, LOW);
00371
00372 | digitalWrite(bluePinRAM, HIGH);
00373 | digitalWrite(greenPinRAM, HIGH);
00374 | digitalWrite(redPinRAM, LOW);
00375
00376 | }
00377 | delay(30);
00378 | }
00379 | for (duty = 255; duty > 0; duty--)
00380 | {
00381 | set_duty(0, duty);
00382 | set_duty(1, duty);
00383 | delay(10);
00384 | }
00385 | pinMode(gaugePinCPU, INPUT);
00386 | pinMode(gaugePinRAM, INPUT);
00387 | delay(1000);
00388 }
00389

### 6.3 main.md File Reference

### 6.4 main.md

00001 # What is aPCmeter? # {#mainpage}
00002
00003 aPCmeter is Arduino Nano 3.0 based device which shows CPU and RAM usage of PC in a vintage looking
way. Here there are some features of the board. Although I included some photos of the hardware, this document is dedicated to the Arduino firmware.
00004
00005 @note For the most up-to-date information, please check the project webpage http://www.alperyazar.com/r/aPCmeter
00006
00007 @image latex aPCmeter_Promo.png
00008
00009 Since my wood working ability is very limited, it has a crude looking wood case. 00010
00011 @image latex aPCmeter_white_annotated_1024_721.jpg My Ugly aPCmeter
00012 @image latex | aPCmeter_1.jpg
00013 @image latex | aPCmeter_2.jpg
00014 @image latex | aPCmeter_6.jpg
00015
00016 # The Overall System Structure # {#the_overall_system_structure}
00017
00018 The overall structure is very simple. A software running on PC computes CPU and RAM usage percentages.
Notice that both CPU and RAM gauges have lighting. Each gauges has its own RGB LED. For example if CPU
usage is low, its gauge is illuminated by only green LED. As CPU usage increases, it is illuminated by both red and green LED resulting a yellow light. In addition to CPU and RAM usage information, PC software calculates lighting. Gauge position and lighting information are independent for Arduino software. PC software sends data over USB based virtual COM port and Arduino displays them. This is how Arduino code works basically. 00019
00020 @note For available PC software, please check the project webpage http://www.alperyazar.com/r/aPCmeter Wtihout a proper PC software, aPCmeter hardware can’t work properly.

### 6.5 state_diagram.md File Reference

### 6.6 state_diagram.md

00001 # State Diagram # {#states}
00002
00003 State diagram is shown in the following figure. 00004
00005 @dotfile state_diagram.gv
00006
00007 Explanations of the states are given as below. 00008
00009 State | Explanation

### 24 CONTENTS

00010 ------------- | -------------
00011 Reset | This is the state after power up. Also setting the program counter (PC) to zero will reset
the CPU. @see resetFunc()
00012 Wait | aPCmeter enters this state after Reset immediately. In this state, "aPCmeter\r\n" message is
sent over serial channel. After the message is sent, aPCmeter waits a response from PC. If no response is received within 2 seconds, 4 pseudo random numbers are generated for PWM values of red LED of CPU gauge, green LED of CPU gauge, red LED of RAM gauge and green LED of RAM gauge. Similarly, 2 pseudo random binary numbers are generated for blue LED of CPU gauge and blue LED of RAM gauge. Using this generated numbers, gauges are illuminated in a pseudo random manner. Gauges stay unpowered completely. Then, the message is sent again.
This loop continues for 60 seconds at most. If a valid message is received from the PC, connection is
considered to be established. If no valid message is received within 60 seconds, _no PC timeout_ is occured and the state is changed from Wait to Silent Wait. @see #_NO_PC_TIMEOUT @see #_UART_TIMEOUT_ms @see wait_for_connection().
00013 Silent Wait | This state is very similar to Wait state. The differences are as in follows. In Silent
Wait state, green and blue LEDs of both gauges become off. Brightness of both red LEDs are changed at every 2 seconds pseudo randomly. As in Wait state, "aPCmeter\r\n" message is sent over serial channel and a valid response is expected. However, Silent Wait state continues until a valid response is received. Notice that Wait and Silent Wait states are almost the same. Purpose of the Wait state is to indicate that aPCmeter is running and is waiting a connection response from PC. Also all LEDs are illimunated in pseudo random manner to test all of them. If aPCmeter is powerd up but no PC software gives a response, changing colors of gauges continuously may disturb people around aPCmeter. Therefore aPCmeter enters in Silen Wait mode after 60 seconds. If you look at directly, you may see that it still tries to connect to PC. @see wait_for_connection()
00014 Active | This is the state where aPCmeter does its job. After connection is established, aPCmeter
works in active state until power is removed. The serial communciation protocol between Arduino and PC is given in the following chapters. In this state, maximum duration between two consecutive successful command should be less than 2 seconds. If aPCmeter doesn’t receive a successful command within 60 seconds, it resets
itself. @see loop() @see #_NO_CMD_TIMEOUT @see #_UART_TIMEOUT_ms

### 6.7 uart_protocol.md File Reference

### 6.8 uart_protocol.md

00001 # UART Protocol # {#uart}
00002
00003 UART protocol works on 9600/8-N-1.
00004
00005 aPCmeter is a command driven device. In other words, PC software sends commands to aPCmeter, it does
its job and acknowledges the PC software. Next command should send after the previous one is acknowledged. Each command starts with a capital letter followed by data of command and ends with small case of the starting letter. If it is desired after the last small case letter ’E’ character can be send. E stands for end. When aPCmeter receives the ’E’ character, it starts to parse the command immediately. If no ’E’ is sent after
the command, aPCmeter may wait at most 2 seconds before start to process the sent command. It is advised to end all comands with ’E’ to trigger the command processing.
00006
00007 Here is the list of all possible messages:
00008
00009 ## Hello Mesage (Dir: aPCmeter -> PC)
00010 A hello message is sent from aPCmeter when it is in Wait or Silent Wait state periodically. Here is
the message: "aPCmeter\r\n", total of 10 bytes. If PC software ready, it should respond with Start Message. 00011
00012 ## Start Message (Dir: PC -> aPCmeter)
00013 This message is meaningful when aPCmeter is in Wait or Silent Wait state. It should be send from the
PC when aPCmeter sends the Hello Message. It consists of 2 (+1 optional ending) bytes
00014
00015 Byte 1 | Byte 2 | Byte 3
00016 ------ | ------ | ----------------
00017 ’S’ | | ’s’ | | ’E’ (Optional)
00018
00019 Response from the aPCmeter:
00020
00021 Byte 1 | Byte 2 | Byte 3 | Byte 4
00022 ------ | ------ | ------ | ------
00023 ’O’ | | ’K’ | | ’\\r’ | | ’\\n’
00024
00025 After the response, LEDs of both gauges stay at green. aPCmeter enters to the Active state and the all following commands may be send without any particular order. In Active state, the PC software should send the following commands with period no less than 2 seconds.
00026
00027 ## PWM Message (Dir: PC -> aPCmeter)
00028 This is the main message to use aPCmeter. It is used to change PWM values of gauges and LEDs. Here is the structure
00029
00030 Byte Number | Message |
00031 ------ | ------
00032 1 | ’P’
00033 2-4 | PWM value of red LED of CPU gauge
00034 5-7 | PWM value of green LED of CPU gauge
00035 8-10 | PWM value of CPU gauge
00036 11-13 | PWM value of red LED of RAM gauge
00037 14-16 | PWM value of green LED of RAM gauge
00038 17-19 | PWM value of RAM gauge

6.8 uart_protocol.md | 25
00039 20 | ’p’
00040 21 | ’E’ (Optional)
00041
00042 Each PWM value is 3 byte length string without null termination like "100", "001", "245". Values
should between 0 and 255 (including the both limits) otherwise they are truncated. All PWM values are updated with this command. This is the way to change color and position of gauges.
00043
00044 For LEDs, "000" corresponds to full bright LED and "255" corresponds to completely off LED. For
gauges, it is the opposite. "000" corresponds to no movement whereas "255" corresponds to full deflection. 00045
00046 Response from the aPCmeter:
00047
00048 Byte 1 | Byte 2 | Byte 3 | Byte 4
00049 ------ | ------ | ------ | ------
00050 ’O’ | | ’K’ | | ’\\r’ | | ’\\n’
00051
00052 ## Test Message(Dir: PC -> aPCmeter)
00053 It is used to start built-in self-test routine. In this routine both gauges are moved slowly and color of gauges are changed slowly. This may be used to check functional operation of aPCmeter.
00054
00055 Byte 1 | Byte 2 | Byte 3
00056 ------ | ------ | ----------------
00057 ’T’ | | ’t’ | | ’E’ (Optional)
00058
00059 Response from the aPCmeter after self-test: 00060
00061 Byte 1 | Byte 2 | Byte 3 | Byte 4
00062 ------ | ------ | ------ | ------
00063 ’O’ | | ’K’ | | ’\\r’ | | ’\\n’
00064
00065 ## Blue Message(Dir: PC -> aPCmeter)
00066
00067 Blue LEDs are not PWM driven and they are not controlled by the PWM command. There are seperate command for blue LEDs just to turn them on or off seperately.
00068
00069 Byte 1 | Byte 2 | Byte 3 | Byte 4 | Byte 5
00070 ------ | ------ | ------ | ------ | ------
00071 ’B’ | | ’B’ | | CPU Blue LED | | RAM Blue LED | ’E’ (Optional)
00072
00073 x Blue LED: Controls the blue LED of the x gauge. If the corresponding byte is ’1’, the corresponding blue LED becomes on. Similarly, if the byte is ’0’ the corresponding LED becomes off.
00074
00075 Response from the aPCmeter:
00076
00077 Byte 1 | Byte 2 | Byte 3 | Byte 4
00078 ------ | ------ | ------ | ------
00079 ’O’ | | ’K’ | | ’\\r’ | | ’\\n’
00080
00081 ## Reset Message(Dir: PC -> aPCmeter)
00082 It is used to reset the aPCmeter. State is changed from Active to Reset after this command. 00083
00084 Byte 1 | Byte 2 | Byte 3
00085 ------ | ------ | ----------------
00086 ’R’ | | ’r’ | | ’E’ (Optional)
00087
00088 Response from the aPCmeter:
00089
00090 Byte 1 | Byte 2 | Byte 3 | Byte 4
00091 ------ | ------ | ------ | ------
00092 ’O’ | | ’K’ | | ’\\r’ | | ’\\n’
00093
00094 ## Keep Alive Message(Dir: PC -> aPCmeter)
00095 It is used to avoid _No CMD Timouet_. As stated previously, PC software should send messages to
aPCmeter periodically to avoid timeout. If PC software has nothing to say, it can just send Keep Alive Message. It does nothing except avoiding timeout.
00096
00097 Byte 1 | Byte 2 | Byte 3
00098 ------ | ------ | ----------------
00099 ’K’ | | ’k’ | | ’E’ (Optional)
00100
00101 Response from the aPCmeter:
00102
00103 Byte 1 | Byte 2 | Byte 3 | Byte 4
00104 ------ | ------ | ------ | ------
00105 ’O’ | | ’K’ | | ’\\r’ | | ’\\n’

## Index

_NO_CMD_TIMEOUT
aPCmeter.ino, 12
_NO_PC_TIMEOUT
aPCmeter.ino, 12
_UART_BAUD_RATE
aPCmeter.ino, 13
_UART_TIMEOUT_ms
aPCmeter.ino, 13

aPCmeter.ino, 10, 20
_NO_CMD_TIMEOUT, 12
_NO_PC_TIMEOUT, 12
_UART_BAUD_RATE, 13
_UART_TIMEOUT_ms, 13
bluePinCPU, 17
bluePinRAM, 17
gaugePinCPU, 18
gaugePinRAM, 18
greenPinCPU, 18
greenPinRAM, 18
loop, 14
RX_buf, 19
redPinCPU, 19
redPinRAM, 19
resetFunc, 19
self_test, 14
set_duty, 15
setup, 16
str2duty, 16
wait_for_connection, 17

bluePinCPU
aPCmeter.ino, 17
bluePinRAM
aPCmeter.ino, 17

gaugePinCPU
aPCmeter.ino, 18
gaugePinRAM
aPCmeter.ino, 18
greenPinCPU
aPCmeter.ino, 18
greenPinRAM
aPCmeter.ino, 18

loop
aPCmeter.ino, 14

main.md, 23

RX_buf
aPCmeter.ino, 19
redPinCPU
aPCmeter.ino, 19
redPinRAM
aPCmeter.ino, 19
resetFunc

aPCmeter.ino, 19

self_test
aPCmeter.ino, 14
set_duty
aPCmeter.ino, 15
setup
aPCmeter.ino, 16
state_diagram.md, 23
str2duty
aPCmeter.ino, 16

uart_protocol.md, 24

wait_for_connection
aPCmeter.ino, 17

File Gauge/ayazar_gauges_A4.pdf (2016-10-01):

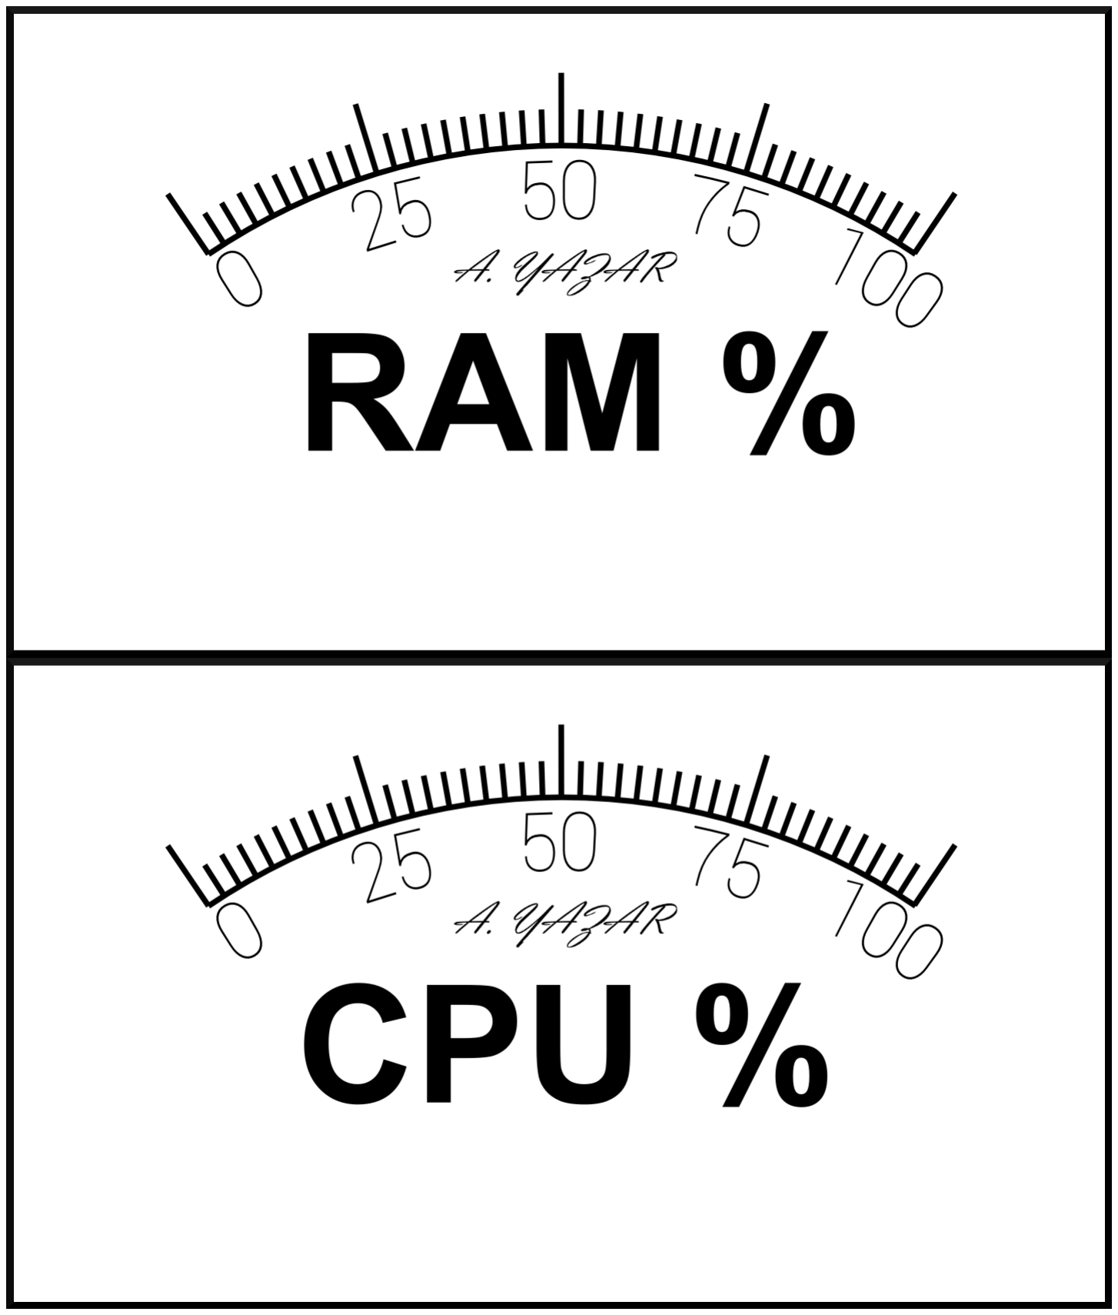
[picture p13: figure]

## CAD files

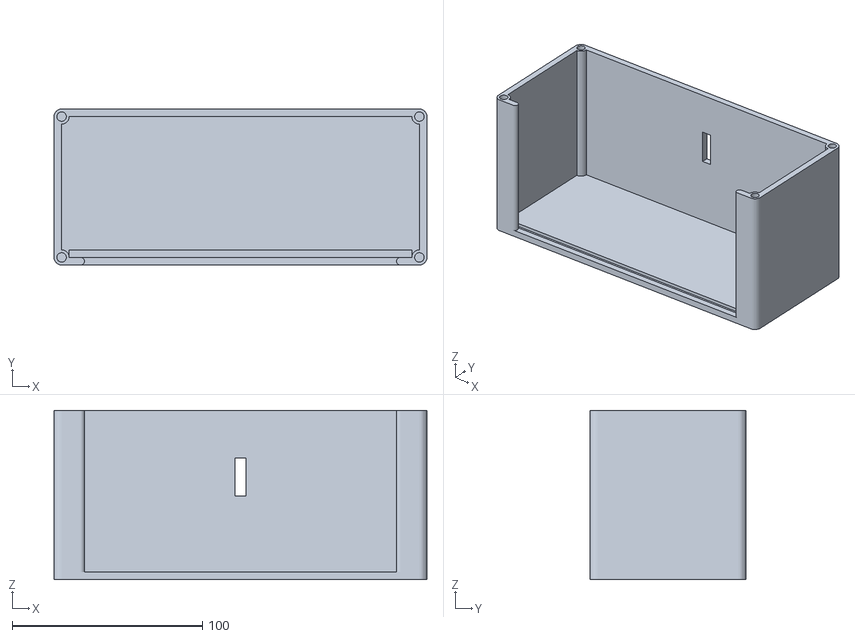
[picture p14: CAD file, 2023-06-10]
3D/body.stl
196.0 x 82.0 x 89.0

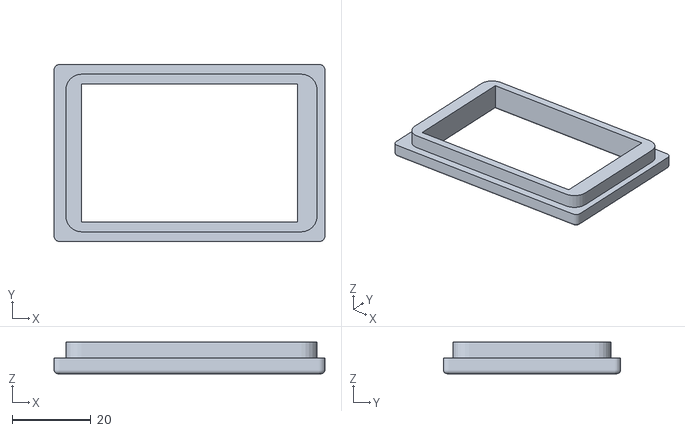
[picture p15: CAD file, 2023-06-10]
3D/eye.stl
68.8 x 45.0 x 8.00

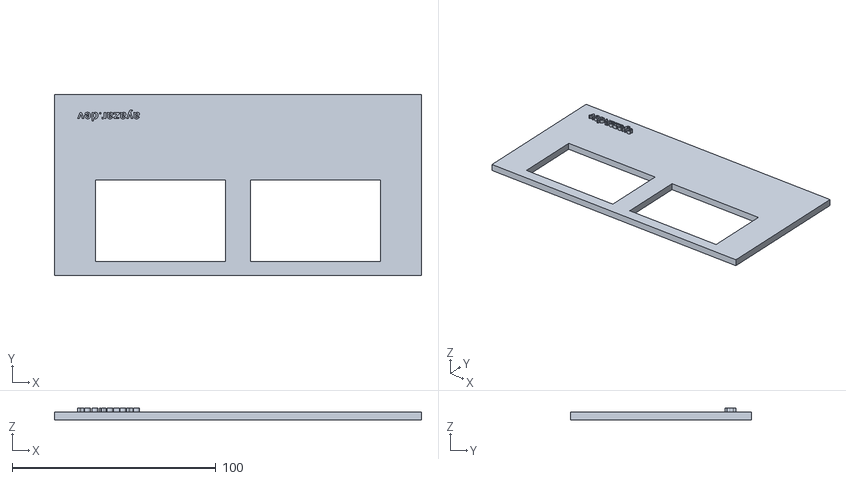
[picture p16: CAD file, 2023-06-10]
3D/front.stl
180.0 x 88.9 x 6.00

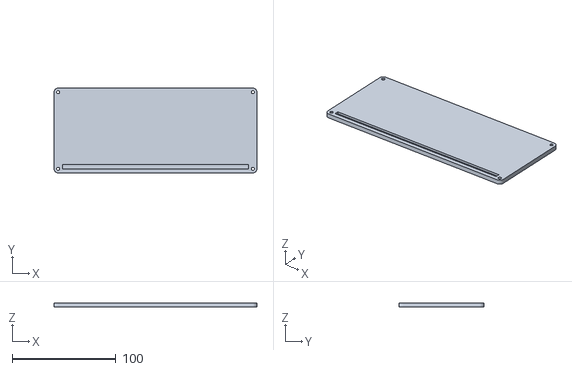
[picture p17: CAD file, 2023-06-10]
3D/bottom.stl
196.0 x 82.0 x 4.00

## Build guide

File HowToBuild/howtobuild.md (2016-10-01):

# How to build your own aPCmeter

First of all, **please download project files from the link given in the main project page:** [http://www.alperyazar.com/r/aPCmeter](http://www.alperyazar.com/r/aPCmeter). You should look into relevant folders when you need.

## Analog gauges

Firstly, you should find two propoer analog gauges for this project. This may be the hardest part to find. Appereance of gauges isn't important. Since the Arduino board will apply a voltage between 0 - 5V, gauges should handle this range. I used 5V analog voltmeters but if you couldn't find a 5V voltmeter you may still use what you find. Because most of high range meters have internal voltage dividers. You can modify the range if you play those internal resistor.

I bought couple of gauges from Aliexpress: [http://www.aliexpress.com/item/HOT-SALE-E-Direct-Current-0-5-V-White-Voltmeter-Analog-Panel-Meter/32521001902.html](http://www.aliexpress.com/item/HOT-SALE-E-Direct-Current-0-5-V-White-Voltmeter-Analog-Panel-Meter/32521001902.html). Unfortunately the product page is not available at this moment. Here is the screenshot of the page when I order it:

***

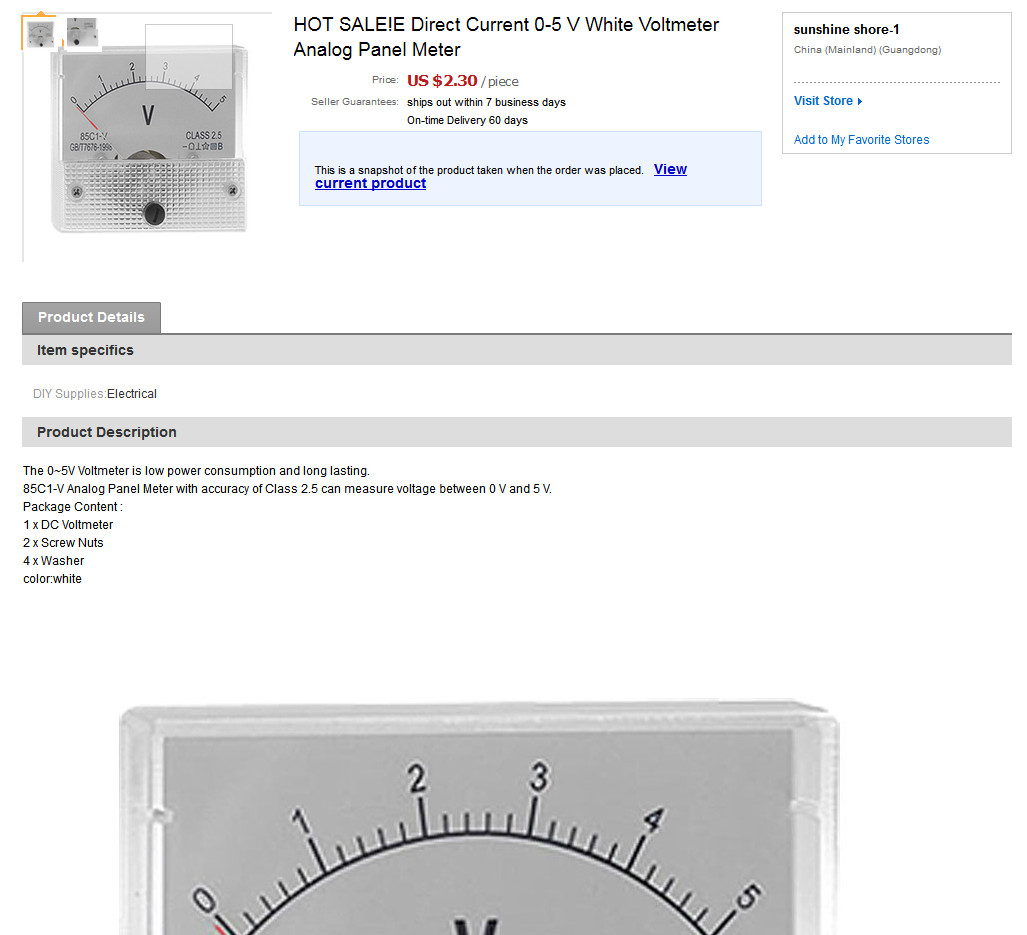
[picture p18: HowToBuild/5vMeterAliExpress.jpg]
I bought two of these gauges from Aliexpress.


***

As I said, there is no single gauge that is only suitable for aPCmeter project. You are free to select anything you want as long as it works as a 5V DC voltmeter panel.

Meters arrived within a month.

***

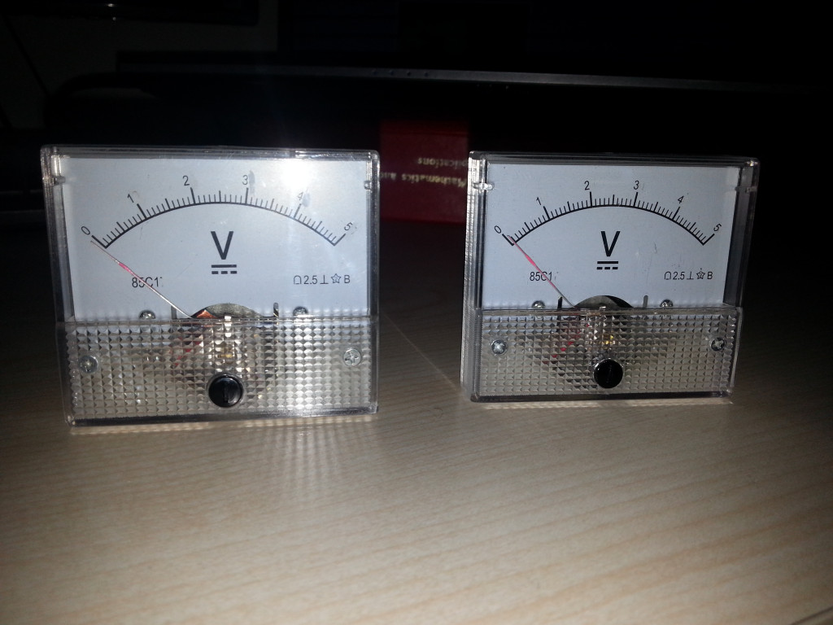
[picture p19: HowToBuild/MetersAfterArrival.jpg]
Analog meters after arrival


***

Next, I designed custom labels. You can find necessary files under "Gauge" folder. Please read the "Readme.md" file. It is very easy to disassemble gauges.

***

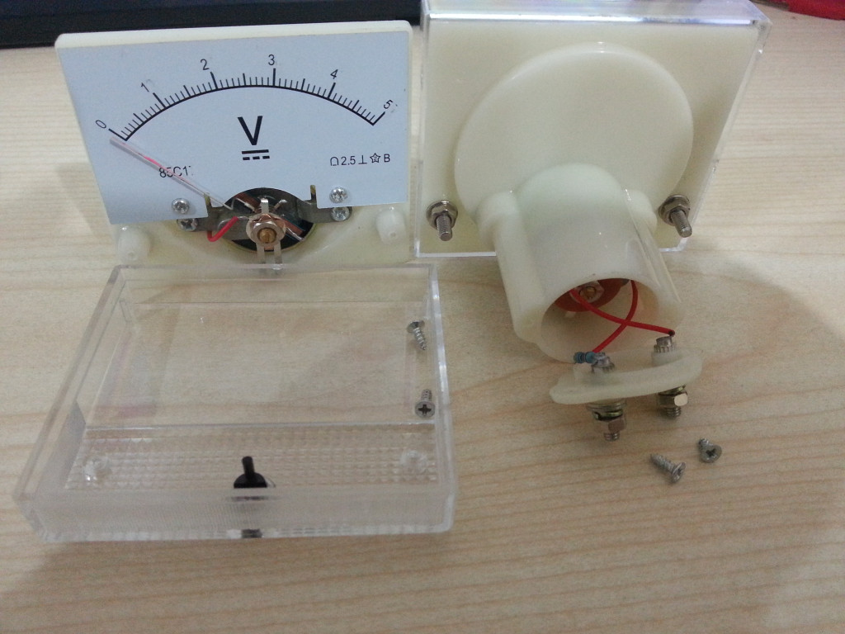
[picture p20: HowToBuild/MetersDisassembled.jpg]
Disassembled meters


***

You don't need to open the back to modify label actually. As you can see, there is a current limiting resistor. Let's remove the front panel.

***

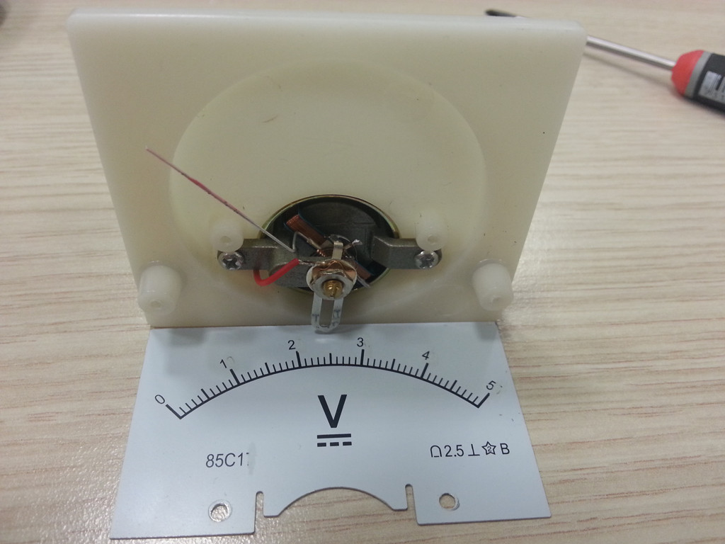
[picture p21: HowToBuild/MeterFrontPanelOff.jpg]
Removed front panel


***

You can use the front and just paste the custom label on it. I prefered to use the back of the panel. I flipped the panel and scratched surface little bit by sandpaper to provide better surface for glue.

***

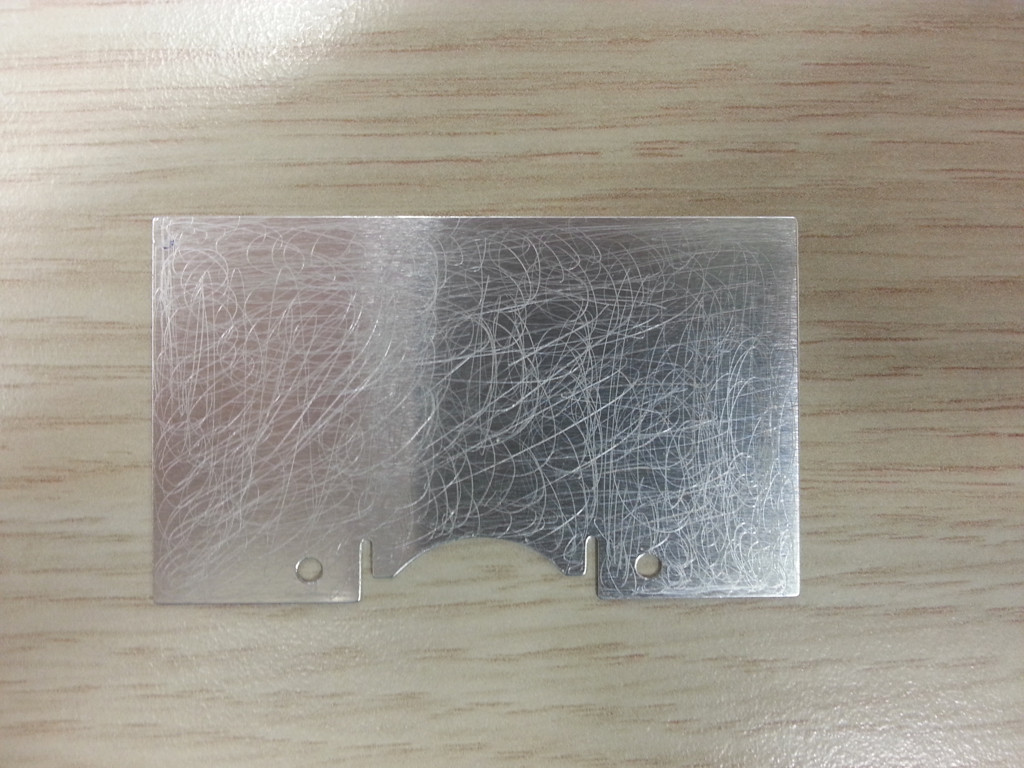
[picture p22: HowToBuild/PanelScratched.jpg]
Scratched panel


***

I used standard A4 paper to print the label. An ordinary paper glue like Pritt is suitable. Let's apply glue.

***

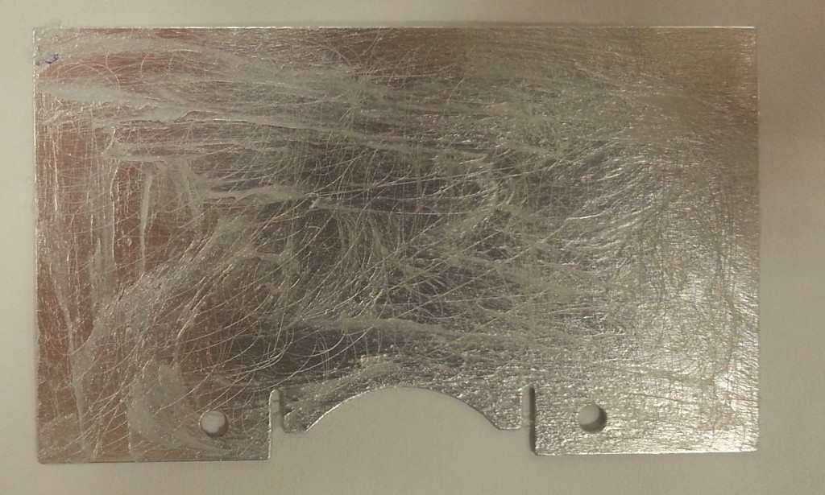
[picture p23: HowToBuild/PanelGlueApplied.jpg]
Glued panel


***

Let's paste our custom label. Dimension of my panel is 60mm x 35mm.

***

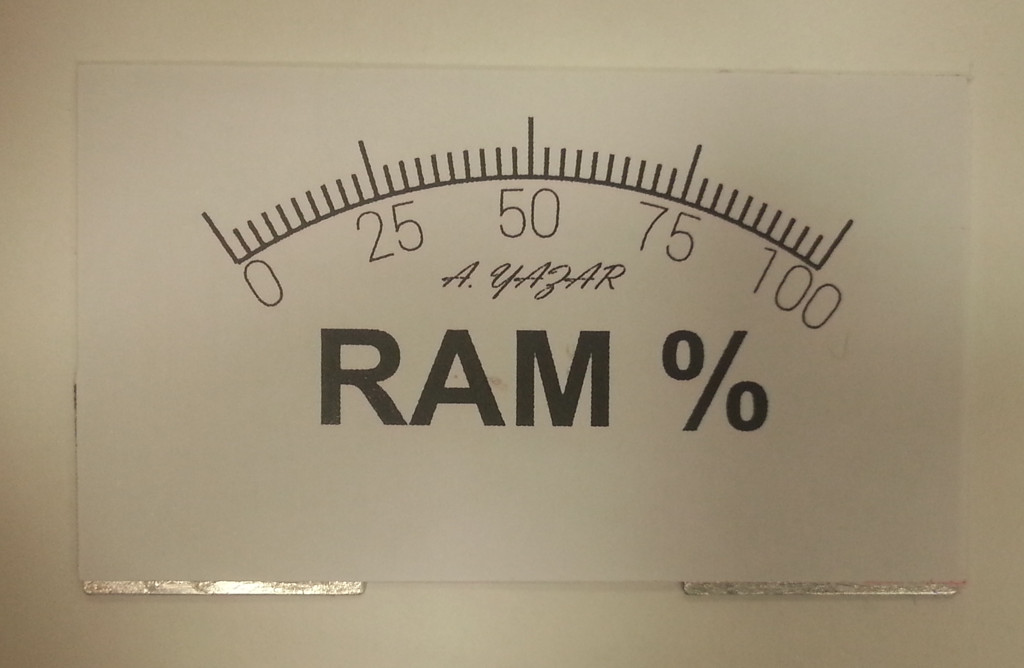
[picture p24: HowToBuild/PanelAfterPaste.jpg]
Panel after paste


***

Let's flip the panel and remove the excess paper using knife or something like it.

***

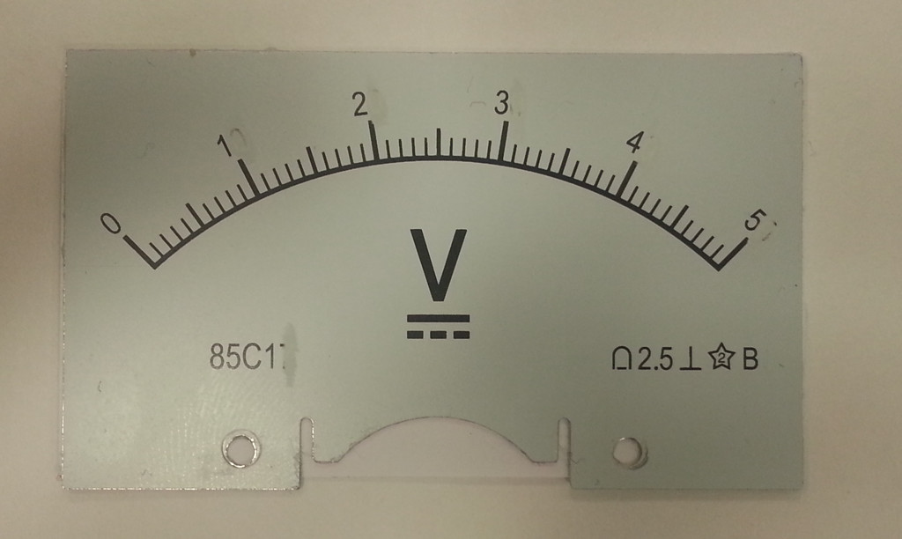
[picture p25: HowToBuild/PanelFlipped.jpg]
Flipped panel


***

After cutting excess paper, it looks like this:

***

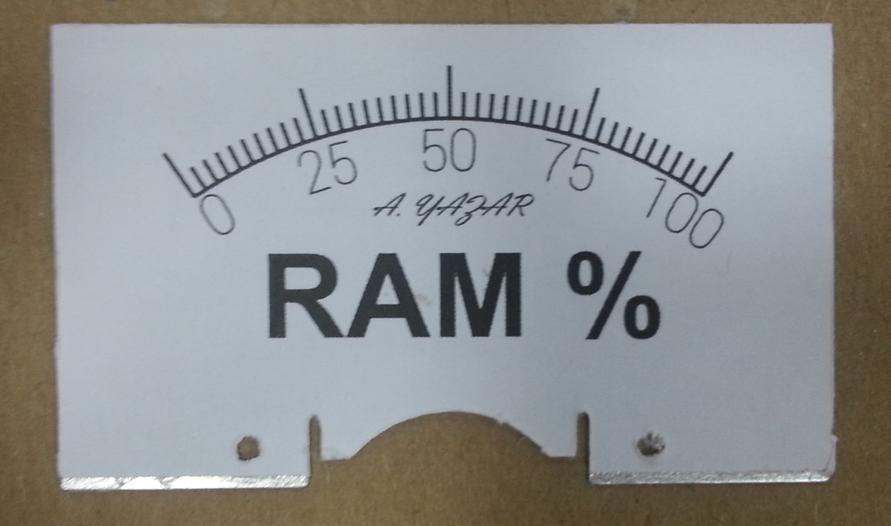
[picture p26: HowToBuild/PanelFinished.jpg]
Finished panel


***

As final step, let's reassemble the guage. Our RAM meter is ready to use now! You should repeat these steps to build CPU meter. 

***

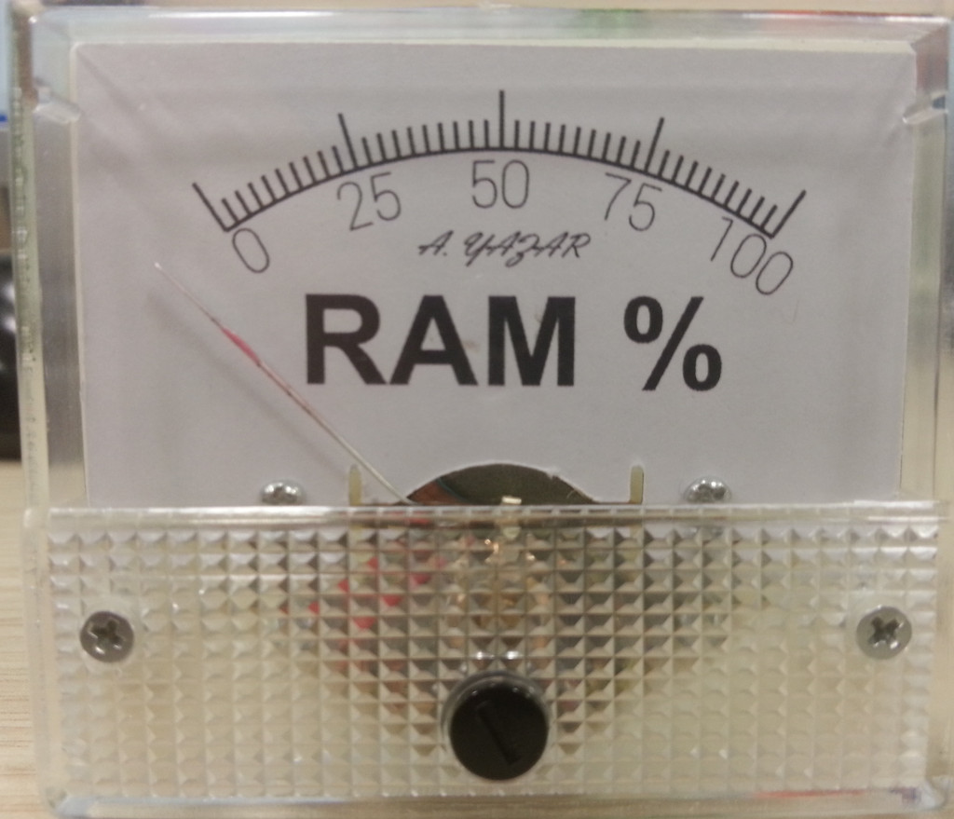
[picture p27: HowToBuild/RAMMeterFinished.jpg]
RAM meter is ready.


***

You can test meter by using the Arduino code itself or a seperate power supply. For example:

***

RAM meter is working.

***

## Arudino based circuit

aPCmeter board consists of Arduino Nano 3.0 + some simple components. You should look at "Board" folder for details. As a reference, here is the my recommended circuit schematic:

***

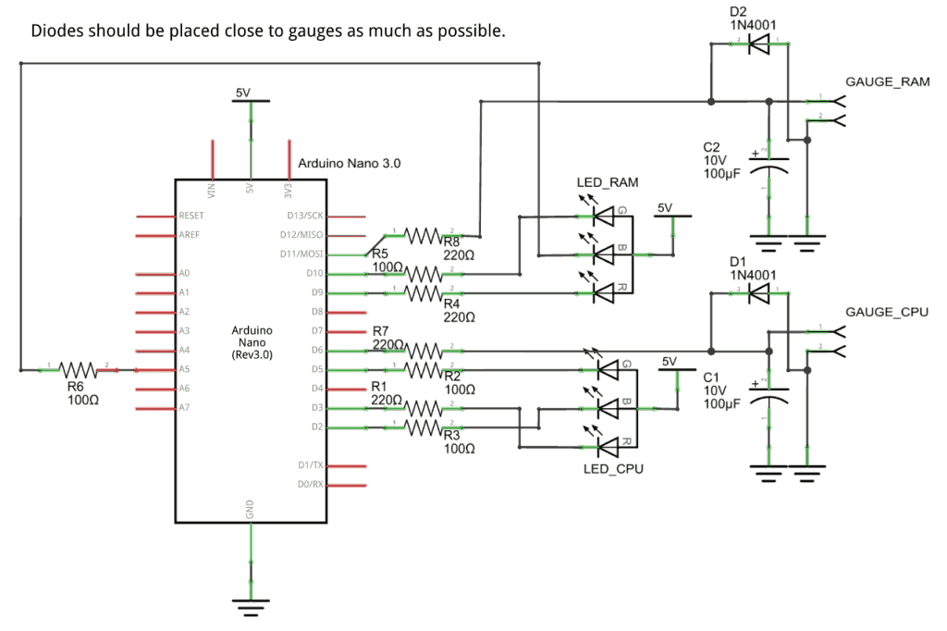
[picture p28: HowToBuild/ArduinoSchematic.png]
Schematic


***

Although I built my aPCmeter using perfboard, I prepared an example layout for breadboard.

***

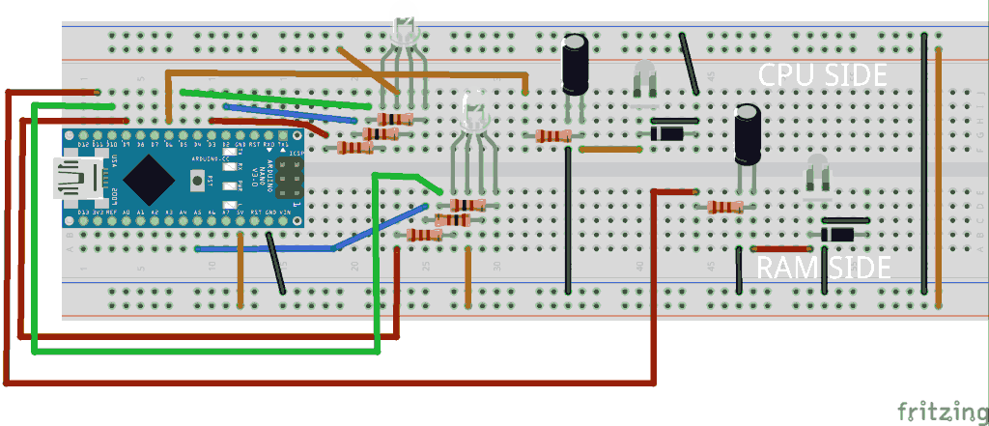
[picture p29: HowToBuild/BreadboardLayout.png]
Breadboard layout


***

The schematic is straightforward. First, I soldered the CPU part and both LEDs as shown in below. Dimension of my perfboard is 125mm x 60mm.

***

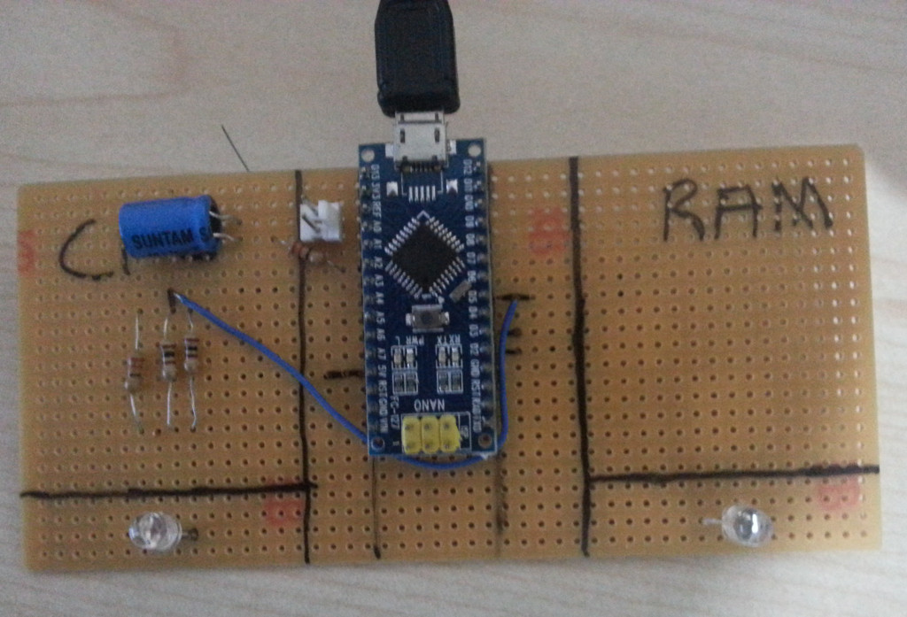
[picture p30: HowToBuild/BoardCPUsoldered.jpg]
CPU part and LEDs are soldered.


***

I checked the LEDs next. Notice that light is not diffused very well. This may be a problem when a gauge is illuminated by both red and green LED to obtain a yellow light. We will do something for diffusion later on.

***

One of the RGB LED is under test.

***

Later I finished the remaining parts of the circuit. I glued (Pritt) piece of aluminium foil around LED and around the meter to improve light reflectivity and to avoid light interference between two gauges. I connected diodes accross terminal of gauges directly. I also prefered to use connectors for gauges.

***

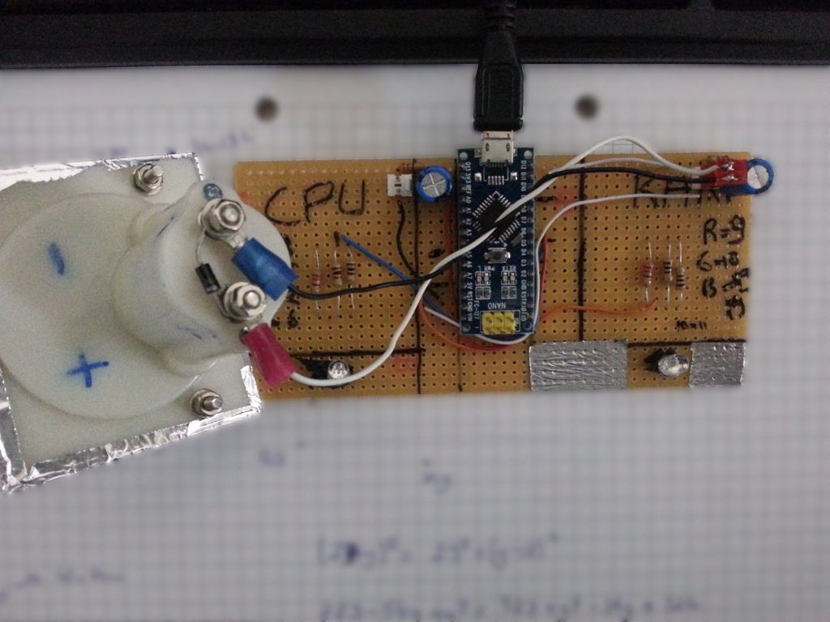
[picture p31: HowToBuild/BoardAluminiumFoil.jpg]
Board is almost complete.


***

Board is almost complete but do you remember the light diffisuion issue? My plan was to illimunate gauges from bottom. Gauge should be illuminated uniformly. This is necessary to obtain secondary colors like yellow properly. I found transparent paper holders around my desk and decided to give a try. They were transparent but had rough surfaces which might provide enough diffusion. I placed couple of paper holders between LED and gauge. You can see the result here for a test pattern. It looks fine.

***

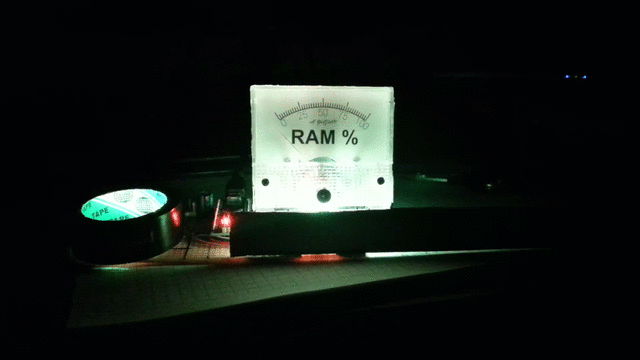
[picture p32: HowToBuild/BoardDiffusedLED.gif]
Lighting after home made diffuser.


***

I took a piece of cardboard and pasted a piece of aluminium foil on one side using a paper glue (Pritt). Then, I cutted into 4 pieces. I prepared one set for each meter.

***

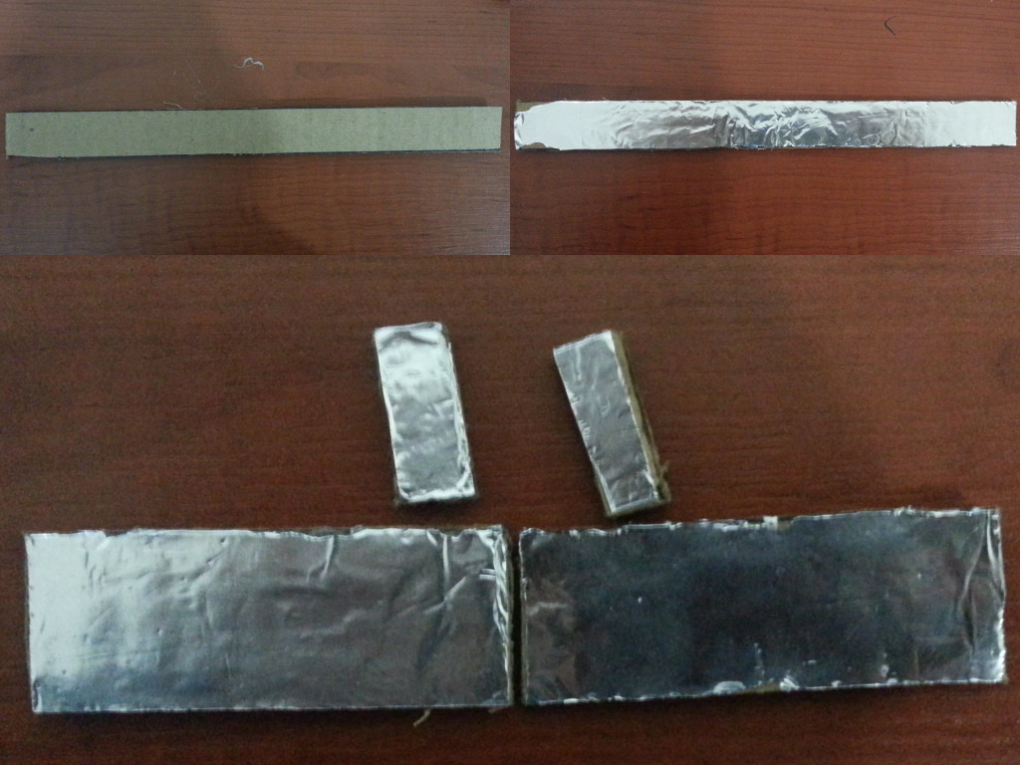
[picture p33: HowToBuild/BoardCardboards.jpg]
Cardboards


***

I glued cardbords around  LEDs to construct a support for meters using hot glue. Foil glued sides should face to LED. I cut small pieces from paper holders and strewed inside support. Finally I glued meters on top of support using hot glue. Here is an example picture. Notice the small pieces inside at the leftmost support. Can you notice a LED? :)

***

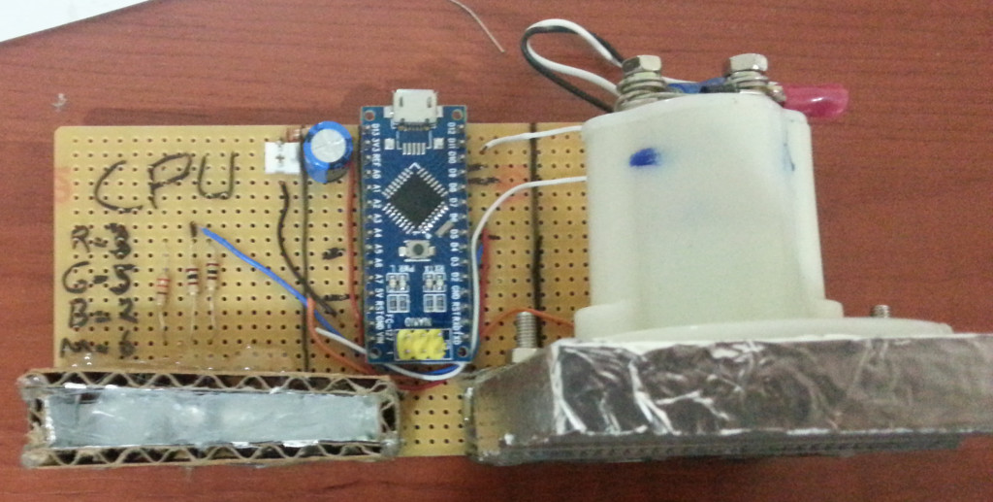
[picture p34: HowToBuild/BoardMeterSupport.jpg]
Home made diffusers inside the meter support


***

As I said before, I used piece of paper holder as light diffuser. Here is the standard paper holder that I used.

***

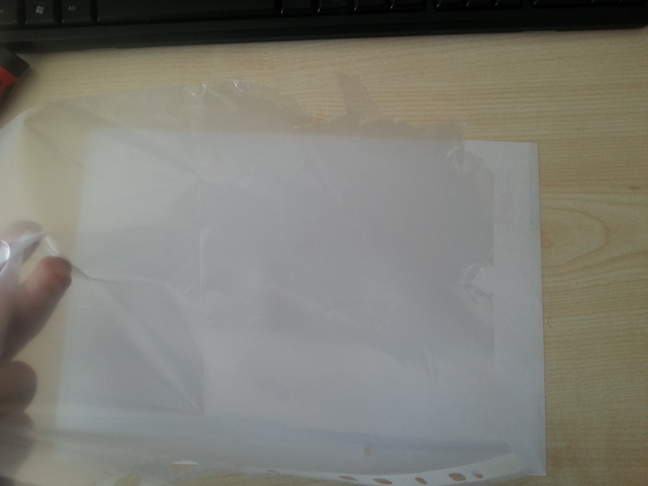
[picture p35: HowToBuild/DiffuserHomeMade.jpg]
Paper holder used to make light diffuser


***

Finally a test pattern works well.

***

Final test

***

## Wood case

This is the most improvised part of the project. I just built a crude wooden box. You can find my cutting layout under "Wood" directory. Here is the quick reference.

***

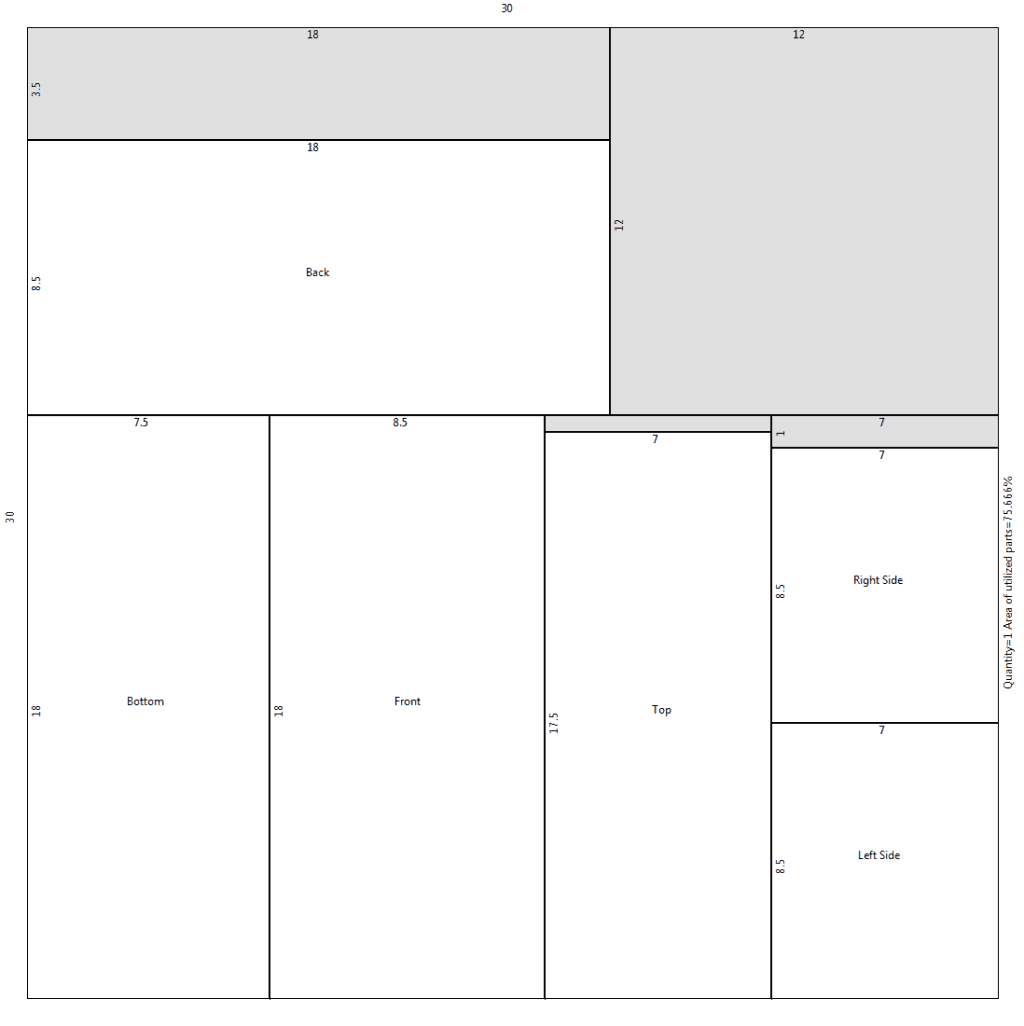
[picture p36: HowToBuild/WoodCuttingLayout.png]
Wood cutting layout


***

I cutted 6 pieces of wood using the given sketch.

***

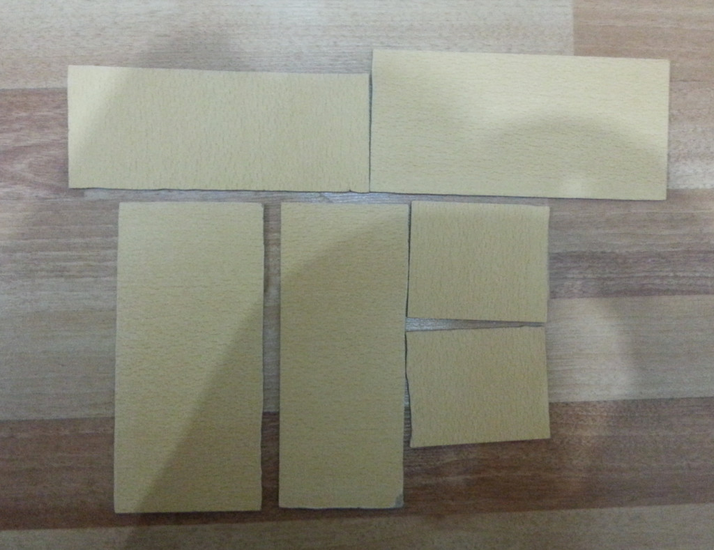
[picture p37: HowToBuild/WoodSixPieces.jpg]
Very rough sides!


***

I chose to build the box in a modular fashion. Instead of glue, I preferred using bracktes and screws to build the box. I drilled holes and screwed brackets.

***

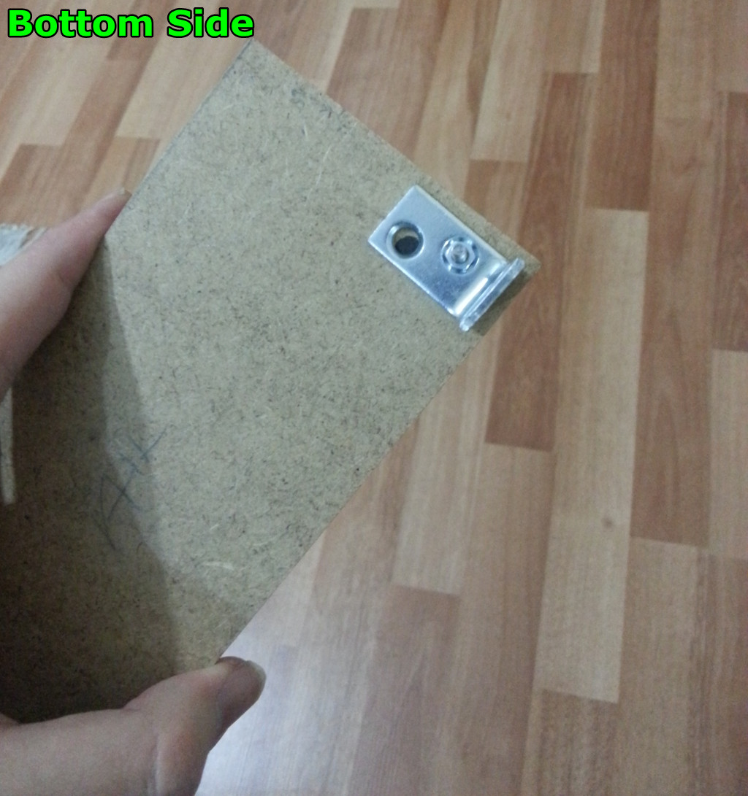
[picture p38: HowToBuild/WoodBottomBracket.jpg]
Screw and bracket


***

***

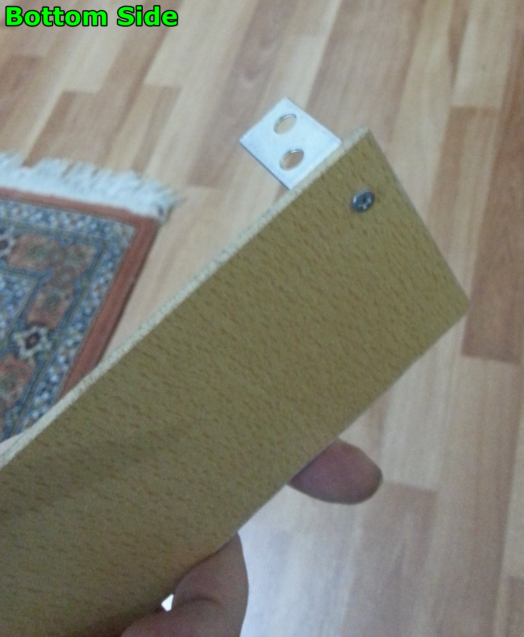
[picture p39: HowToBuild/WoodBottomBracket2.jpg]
Another view of screw and bracket


***

Then I finished all bracktes of the bottom side.

***

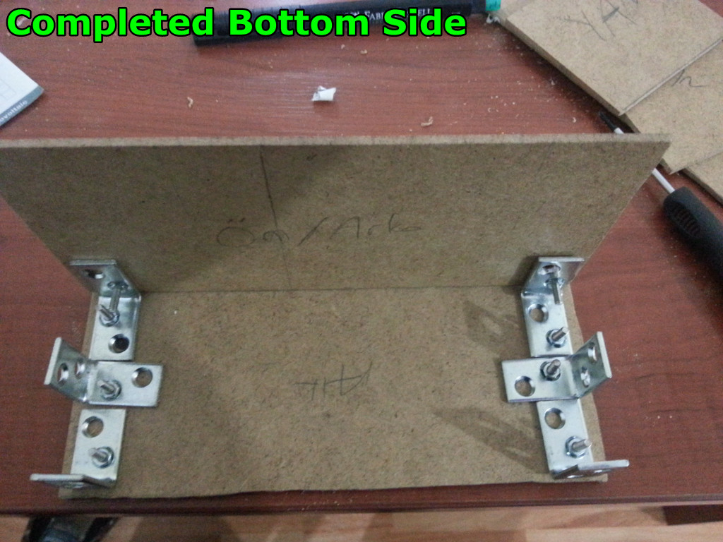
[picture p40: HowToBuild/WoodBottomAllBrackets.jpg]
Brackets of the bottom side


***

After drilling all holes necessary for brackets at the bottom, I mounted the board using three screws.

***

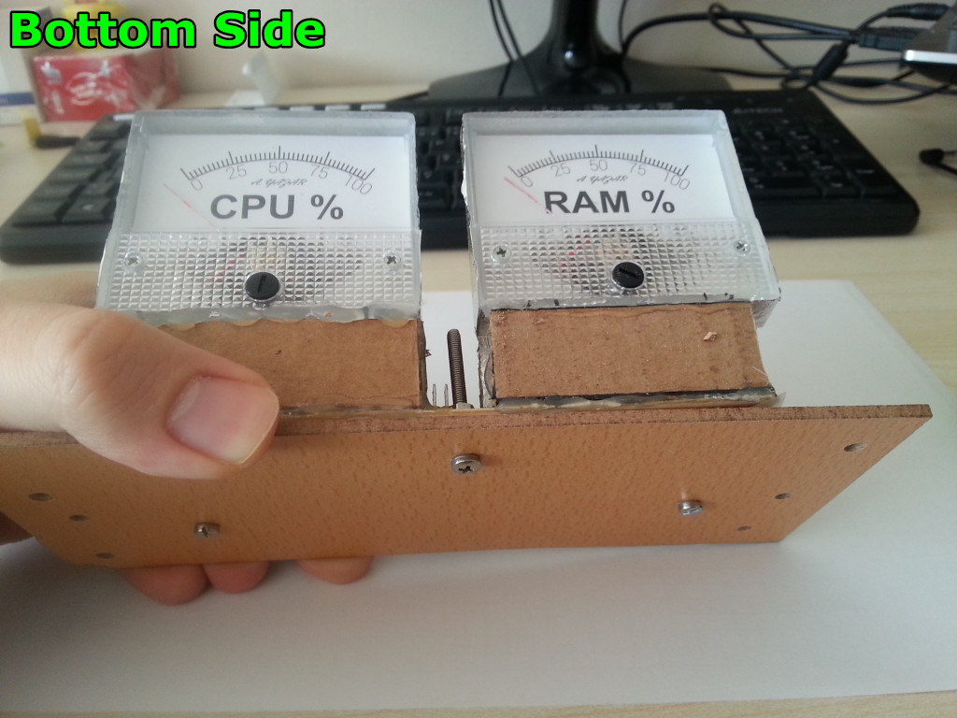
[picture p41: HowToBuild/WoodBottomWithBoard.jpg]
Mounted board


***

I added paper holder between perfboard and screws as an insulation layer to protect circuit from deadshorts.

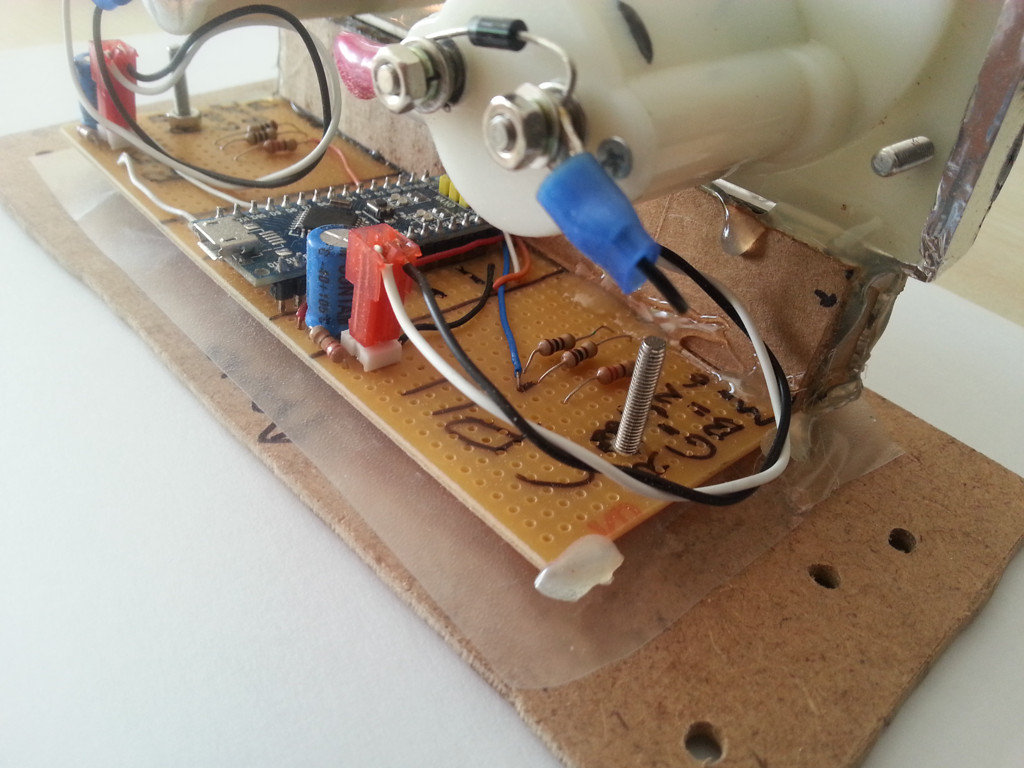
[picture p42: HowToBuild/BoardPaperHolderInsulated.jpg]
Mounted board Insulated Board


***

Then, I completed the remaning sides in a similar way. Now, it is ready to close the box.

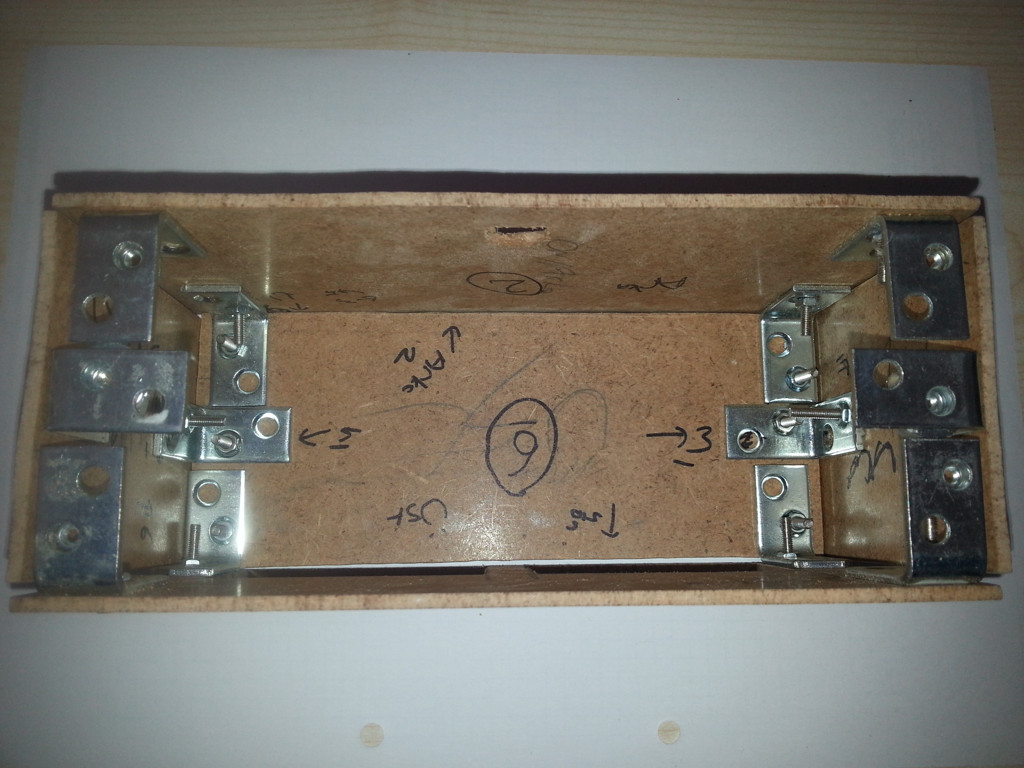
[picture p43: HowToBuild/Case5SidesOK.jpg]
5 sides are completed.


***

Notice that I am using nuts and bolts (trademark warning!) to attach panels together with help of brackets. I held a nut with my hand and tightened bolt with my otherhand. However once I closed the box completely, I couldn't hold nut. Therefore I applied hot glue to nuts (There are 6 of them.) corresponding to screws at the bottom. By this way I was able to tighten the bottom screws without any problem. Once I open the box from using the bottom screws, again I can my other hand to hold other nuts. There is no need to glue for them but it is up to you. Here is the example: 

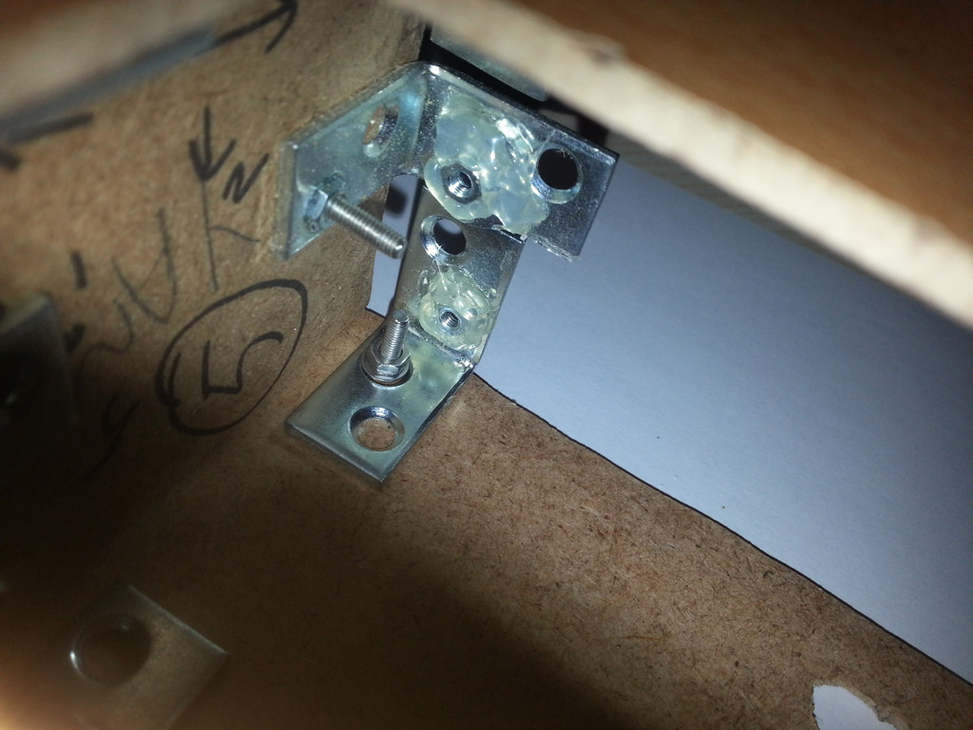
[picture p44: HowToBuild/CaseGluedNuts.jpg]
Glued Nuts


***

As the last step, you should open necessary openings for USB cable and gauges to be able to see them. First, I opened the back panel and simply use pencil to draw skleleton for cuts. I repeated similar steps for USB cable at the back. Here is the final result:

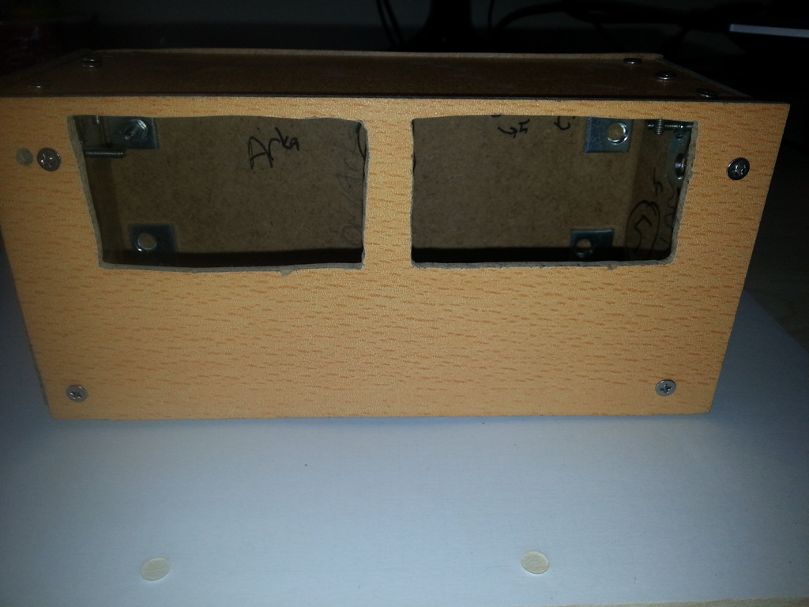
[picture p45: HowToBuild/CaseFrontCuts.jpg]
Front Cuts


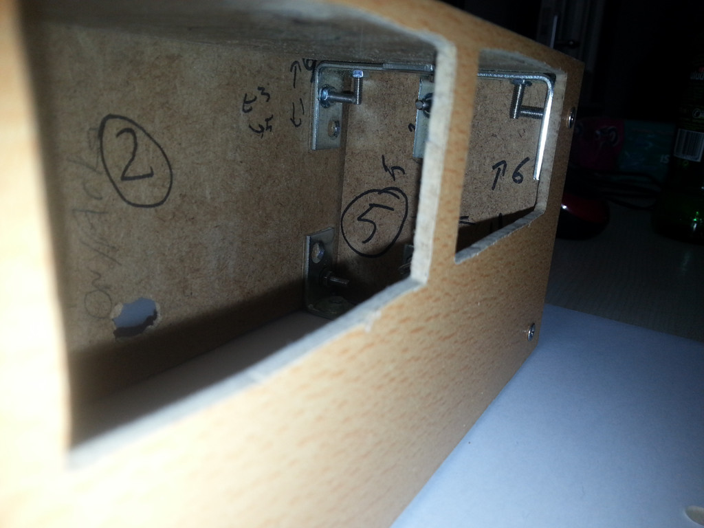
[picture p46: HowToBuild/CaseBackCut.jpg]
Back Cut


***

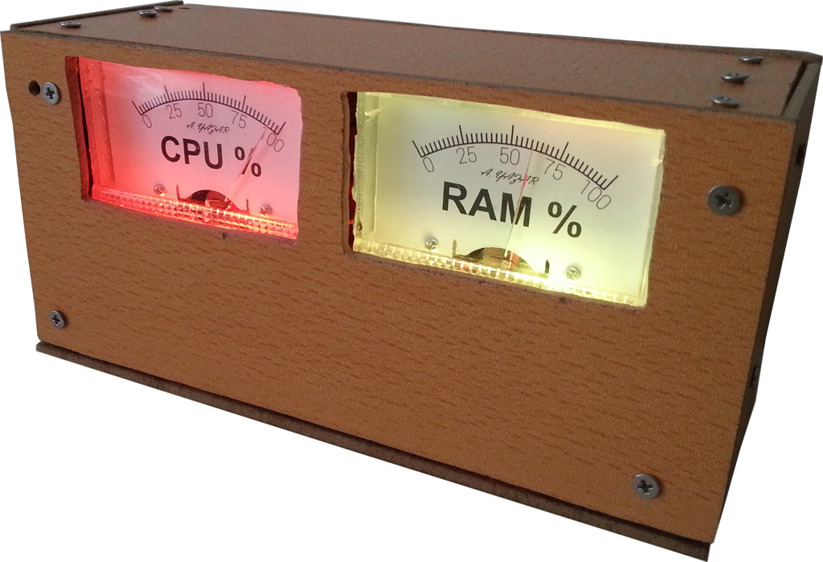
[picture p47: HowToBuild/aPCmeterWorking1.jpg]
Completed aPCmeter


***

## Software

You should upload the Arduino software to your board if you haven't done it yet. Software is located in "Firmware" folder. 

aPCmeter needs also host software running on PC in addition to Arduino software. PC software should monitor CPU and RAM usages, calcute PWM values for gauges and LEDs and communicate with Arduino software over serial channel. This project is for the device (aPCmeter) only. No PC software is located in this project files. If you wish, you can write your own PC software. Currently I am using an experimental and simple software to use it. However, it is far from complete and to publish. I am planning to publish a PC software too. Please check aPCmeter project page [http://www.alperyazar.com/r/aPCmeter](http://www.alperyazar.com/r/aPCmeter) or [http://www.alperyazar.com/outputs.html](http://www.alperyazar.com/outputs.html). Most probably I will also edit this section to link PC software that I published but I may also forget. So if you are looking for ready-to-use PC software (You should definitely have one to be able to use aPCmeter.) please check the given links.

***

# Further Questions and Comments

If you have questions and comments about this project, please feel free to contact me.

[http://www.alperyazar.com/contact.html](http://www.alperyazar.com/contact.html)

*Last Updated: 01 Oct 2016*

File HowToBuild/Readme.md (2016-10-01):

# HowToBuild Folder
This folder contains necessary instructions to build aPCmeter hardware.

## Files
* *howtobuild.html*: This is the file you should read to build aPCmeter. I used pandoc to generate this file from markdown.
* *howtobuild.md*: Source file for howtobuild.html. pandoc is used to generate output .html file.
* *howtobuild.bat*: Small script to call pandoc on Windows.
* *Image files*: They should be at the same directory with howtobuild.html

*C:16396*

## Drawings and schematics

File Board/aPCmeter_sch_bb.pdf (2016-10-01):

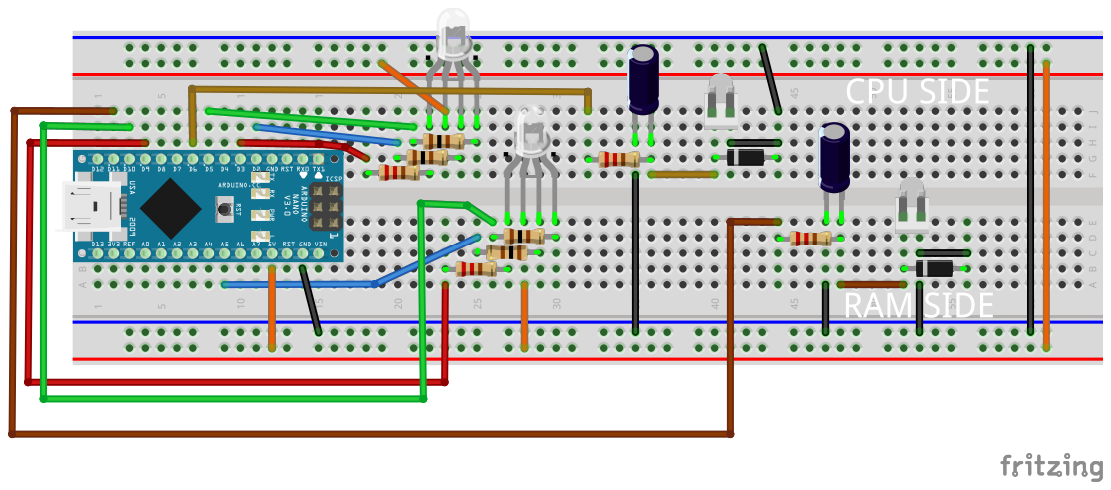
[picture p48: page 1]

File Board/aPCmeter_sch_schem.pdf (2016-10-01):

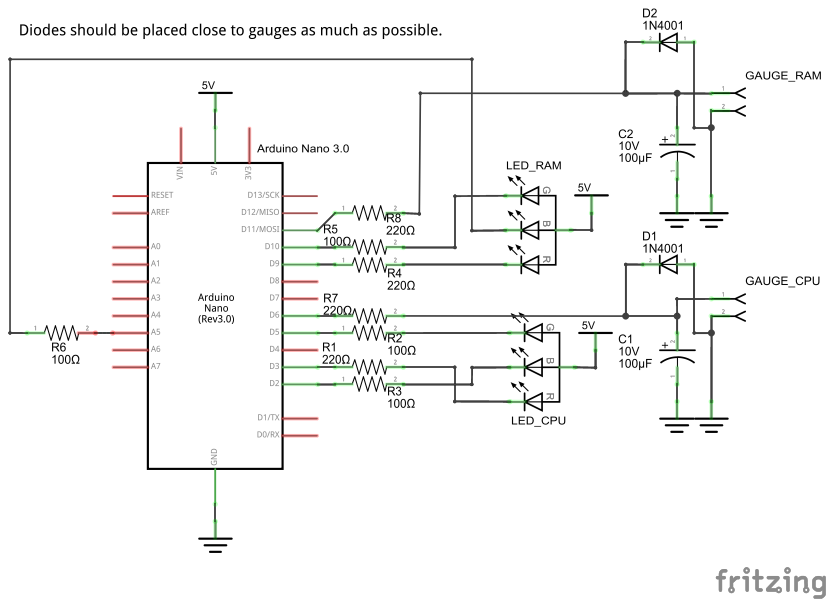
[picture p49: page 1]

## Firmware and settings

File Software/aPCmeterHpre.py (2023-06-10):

import sys
import glob
import serial
import time
import psutil

version ="pre1dev3"

available_ports=[];
connection_check_str = "aPCmeter"
ser = serial.Serial()

cpuPWM0 = 25
cpuPWM100 = 229
ramPWM0 = 25
ramPWM100 = 229

# http://stackoverflow.com/a/14224477/1766391
def serial_ports():
    """ Lists serial port names

        :raises EnvironmentError:
            On unsupported or unknown platforms
        :returns:
            A list of the serial ports available on the system
    """
    if sys.platform.startswith('win'):
        ports = ['COM%s' % (i + 1) for i in range(256)]
    elif sys.platform.startswith('linux') or sys.platform.startswith('cygwin'):
        # this excludes your current terminal "/dev/tty"
        ports = glob.glob('/dev/tty[A-Za-z]*')
    elif sys.platform.startswith('darwin'):
        ports = glob.glob('/dev/tty.*')
    else:
        raise EnvironmentError('Unsupported platform')

    result = []
    for port in ports:
        try:
            s = serial.Serial(port)
            s.close()
            result.append(port)
        except (OSError, serial.SerialException):
            pass
    return result

def connect_to_aPCmeter(port_list):
    ser.baudrate = 9600
    ser.timeout = 3
    ser.dsrdtr = False
    ser.xonxoff = False
    ser.rtscts = False
    ser.parity = serial.PARITY_NONE
    ser.bytesize = serial.EIGHTBITS
    ser.stopbits = serial.STOPBITS_ONE
    
    for port in port_list:
        ser.port = port
        try:
            print "Trying " + port
            ser.open()
            ser.reset_input_buffer()
            ser.reset_output_buffer()
            read_value = ser.read(size=100)
            print read_value
            print type(read_value)
            print len(read_value)
            
            if (len(read_value)>9):
                if connection_check_str in read_value:
                    print "aPCmeter is found at " + port
                    initialize_aPCmeter()
            else:
                print "NO aPCmeter is found at" + port
                ser.close()
            
        except (OSError, serial.SerialException):
            pass

    return False

def initialize_aPCmeter():
    print "Starting the aPCmeter..."
    print ser.write('SsE'.encode('ascii'));
    ser.flush()
    read_value = ser.read(4)
    if (len(read_value)>3):
        if "OK" in read_value:
            print "aPCmeter is initialized."
            run_aPCmeter()
            
def run_aPCmeter():
    
    while True:
        ser.reset_input_buffer()
        ser.reset_output_buffer()
		
        cpu = psutil.cpu_percent(interval=1, percpu=False)
        ram = psutil.virtual_memory().percent
        
        cpu_pwm = int(cpuPWM0 + (cpu / 100.0) * (cpuPWM100 - cpuPWM0))
        ram_pwm = int(ramPWM0 + (ram / 100.0) * (ramPWM100 - ramPWM0))
        
        if cpu_pwm < 0:
            cpu_pwm = 0
        if cpu_pwm > 255:
            cpu_pwm = 255
        
        if ram_pwm < 0:
            ram_pwm = 0
        if ram_pwm > 255:
            ram_pwm = 255
            
        cpuPWMg = int(255 * cpu/100)
        cpuPWMr = 255 - cpuPWMg
        
        if cpuPWMr < 0:
            cpuPWMr = 0
        if cpuPWMr > 255:
            cpuPWMr = 255
        
        if cpuPWMg < 0:
            cpuPWMg = 0
        if cpuPWMg > 255:
            cpuPWMg = 255
        
        
        ramPWMg = int(255 * ram/100)
        ramPWMr = 255 - ramPWMg
        
        if ramPWMr < 0:
            ramPWMr = 0
        if ramPWMr > 255:
            ramPWMr = 255
        
        if ramPWMg < 0:
            ramPWMg = 0
        if ramPWMg > 255:
            ramPWMg = 255
        
          
        msg = 'P'
        msg += "%03d" % (cpuPWMr)
        msg += "%03d" % (cpuPWMg)
        msg += "%03d" % (cpu_pwm)
        msg += "%03d" % (ramPWMr)
        msg += "%03d" % (ramPWMg)
        msg += "%03d" % (ram_pwm)
        msg += 'pE'
        
        
        print "******"
        print "CPU %d" % (int(cpu))
        print "MEM %d" % (int(ram))
        print msg
        print ""
        
        ser.write(msg.encode('ascii'));
        ser.flush()
        read_value = ser.read(4)
        print read_value
        if "OK" not in read_value:
		    print 'Wrong ACK after RAM/CPU info'
		    return

if __name__ == '__main__':
    print "aPCmeterHpre " + version
    while True:
        print "Searching available ports..."
        available_ports = serial_ports()
        if not available_ports:
            print "No port is found"
        else:
            print 'Available Ports: ' + ', '.join(available_ports)
            if(connect_to_aPCmeter(available_ports) == False):
                print "There is no aPCmeter connected to this machine."
        
        
        try:
            ser.close()
        except e:
            pass
        time.sleep(1)

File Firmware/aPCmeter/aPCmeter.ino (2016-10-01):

/*!
 * @file aPCmeter.ino
 * @brief aPCmeter Project, source code of Arduino firmware.
 * @details This single file contains all source code of aPCmeter Arduino Nano firmware. It is tested by using Arduino IDE v1.6.7 on Windows 7 x64.
 * @author Alper Yazar
 * @version s1
 * @date 2016-05-08
 * @copyright CC BY-NC-SA 4.0 (http://creativecommons.org/licenses/by-nc-sa/4.0/)
 * @bug Visit: https://github.com/alperyazar/aPCmeter/issues to check existing bugs or to report a new one.
 * @warning NO WARRANTY! AS IS!
 * @see The Official Project Page: http://www.alperyazar.com/r/aPCmeter
 */

 /*!
  * @brief Determines the maximum trials between two consecutive command reception in active state before reset.
  * @details When aPCmeter is in active state, it waits commands from PC. PC software should send commands with period less than #_UART_TIMEOUT_ms to avoid time out. If no valid message is received within #_UART_TIMEOUT_ms msec after the last successfully received command, a timeout counter is incremented by one. If value of this counter exceeds #_NO_CMD_TIMEOUT, aPCmeter resets itself.
  * @see loop()
  * @verbatim Maximum duration between two successful message before reset in msec =  
(#_NO_CMD_TIMEOUT + 1) x #_UART_TIMEOUT_ms @endverbatim
  * @warning It should be a non-negative integer.
  */
#define _NO_CMD_TIMEOUT 29

/*!
 * @brief Determines the duration of wait state after reset.
 * @details After reset, aPCmeter sends "aPCmeter" message periodically determined by #_UART_TIMEOUT_ms. After each message it waits a valid message from PC for the first connection. At each time "aPCmeter" message is sent, a pseudo random color is selected for both CPU and RAM gauges and both gauges are illuminated with the selected color. This is used to indiciate that aPCmeter is looking for a PC connection and to provide pseudo random test pattern sequence for all three channels (R, G, B) of both LEDs. If the number of trials exceeds the threshold value determined by #_NO_PC_TIMEOUT, aPCmeter enters to the silent wait state. In that state, G and B LEDs of both gauges become off. Only brightness of R LEDs of both gauges is changed in a pseudo random manner. This is done to avoid disturbing color changes when all R, G, B LEDs are illuminated pseudo randomly. This may be the case when aPCmeter is left connected to the PC or another USB host device. However brightness of red LEDs continues to change and aPCmeter looks a PC connection for ever. One may still be able to notice that aPCmeter is active since brightness of red LEDs is changed periodically.
 * @note Duration of wait state can be calculated as follow
 * @verbatim Duration of wait state in msec =  (#_NO_PC_TIMEOUT + 1) x #_UART_TIMEOUT_ms @endverbatim
 * @warning It should be a non-negative integer.
 * @see wait_for_connection()
 */
#define _NO_PC_TIMEOUT 29

/*!
 * @brief Receive timeout value in msec for serial channel receive function.
 * @details aPCmeter waits at most #_UART_TIMEOUT_ms msec when serial read functions are called. If no message is received from PC in #_UART_TIMEOUT_ms msec, serial receive functions are timed out and code continues. Actually this is basic "tic" source for this code.
 * @warning It should be a non-negative integer.
 * @see setup()
 */
#define _UART_TIMEOUT_ms 2000

/*!
 * @brief Baud rate for serial communication in bps
 * @see setup()
 */
#define _UART_BAUD_RATE 9600

/*!
 * @brief Pin number of red LED of CPU gauge
 * @see http://playground.arduino.cc/Learning/Pins
 */
const int redPinCPU = 3;

/*!
 * @brief Pin number of green LED of CPU gauge
 * @see http://playground.arduino.cc/Learning/Pins
 */
const int greenPinCPU = 5;

/*!
 * @brief Pin number of blue LED of CPU gauge
 * @see http://playground.arduino.cc/Learning/Pins
 */
const int bluePinCPU = 2;

/*!
 * @brief Pin number of CPU gauge
 * @see http://playground.arduino.cc/Learning/Pins
 */
const int gaugePinCPU = 6;

/*!
 * @brief Pin number of red LED of RAM gauge
 * @see http://playground.arduino.cc/Learning/Pins
 */
const int redPinRAM = 9;

/*!
 * @brief Pin number of green LED of RAM gauge
 * @see http://playground.arduino.cc/Learning/Pins
 */
const int greenPinRAM = 10;

/*!
 * @brief Pin number of blue LED of RAM gauge
 * @see http://playground.arduino.cc/Learning/Pins
 */
const int bluePinRAM = 19;

/*!
 * @brief Pin number of RAM gauge
 * @see http://playground.arduino.cc/Learning/Pins
 */
const int gaugePinRAM = 11;

/*!
 * @brief Receive buffer for serial channel
 * @details More than enough actually...
 */
char RX_buf[64];

/*!
 * @brief Tricky reset function. Just set PC to 0.
 */
void(* resetFunc) (void) = 0;

/*!
 * @brief This function is called after startup. Like a well known main() function in C.
 * @see https://www.arduino.cc/en/Reference/Setup
 */
void setup()
{
  pinMode(gaugePinCPU, INPUT);
  pinMode(gaugePinRAM, INPUT);

  digitalWrite(redPinCPU, HIGH);
  digitalWrite(greenPinCPU, HIGH);
  digitalWrite(bluePinCPU, HIGH);

  digitalWrite(redPinRAM, HIGH);
  digitalWrite(greenPinRAM, HIGH);
  digitalWrite(bluePinRAM, HIGH);

  pinMode(redPinCPU, OUTPUT);
  pinMode(greenPinCPU, OUTPUT);
  pinMode(bluePinCPU, OUTPUT);

  pinMode(redPinRAM, OUTPUT);
  pinMode(greenPinRAM, OUTPUT);
  pinMode(bluePinRAM, OUTPUT);

  //All LEDs are off. Gauges are off.
  
  // Set properties of Serial's.
  Serial.setTimeout(_UART_TIMEOUT_ms);
  Serial.begin(_UART_BAUD_RATE);
  while (!Serial) {
    ; // wait for serial port to connect. Needed for native USB
  }
  wait_for_connection();
}

/*!
 * @brief Wait proper connection initialization from PC
 */
void wait_for_connection()
{
  int timeout = 0;

  // Try to randomize pseudo-random sequences used by random() funtion.
  randomSeed(analogRead(0));
  while (1)
  {
    Serial.println("aPCmeter");
    if ( Serial.readBytesUntil('E', RX_buf, 64) == 0)
    {
      analogWrite(redPinCPU, random(256));
      analogWrite(redPinRAM, random(256));
      analogWrite(greenPinRAM, random(256));
      analogWrite(greenPinCPU, random(256));
      digitalWrite(bluePinCPU, random(2));
      digitalWrite(bluePinRAM, random(2));
      timeout++;
      if (timeout > _NO_PC_TIMEOUT)
      {
        timeout--;
        digitalWrite(greenPinCPU, HIGH);
        digitalWrite(bluePinCPU, HIGH);
        digitalWrite(greenPinRAM, HIGH);
        digitalWrite(bluePinRAM, HIGH);
        analogWrite(redPinRAM, 128 + random(128));
        analogWrite(redPinCPU, 128 + random(128));
      }
    }
    else
    {
      if ((RX_buf[0] == 'S') && (RX_buf[1] == 's'))
      {
        timeout = 0;
        digitalWrite(redPinCPU, HIGH);
        digitalWrite(redPinRAM, HIGH);
        digitalWrite(bluePinCPU, HIGH);
        digitalWrite(bluePinRAM, HIGH);
        digitalWrite(greenPinCPU, LOW);
        digitalWrite(greenPinRAM, LOW);
		// Both gauges are fully green.
        Serial.println("OK");
        return;
      }
      memset(RX_buf, ' ', 64); //Clear all buffer
    }
  }
}
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

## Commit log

2016-10-01 This is the first version. (s1)
    [aPCmeter_sch.fzz]
2023-06-10 v2 (#1)
    v2, 2023 (3D printed box) is published with PC software addition and minor corrections.
    [body.stl, bottom.stl, eye.stl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]
